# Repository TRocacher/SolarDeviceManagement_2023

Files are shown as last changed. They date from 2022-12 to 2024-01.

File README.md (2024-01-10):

Ce dépôt, en construction, détaille la conception d'un système de pilotage de climatiseurs en fonction de l'excédent de puissance photovoltaïque pour une maison.
Le système s'appuie sur de l'existant :
- Climatiseurs (4) de type Mitsubishi 2kW
- un installation photovoltaïque avec un onduleur Fronius 6kVA SnapInverter associé à un smartMeter triphasé en point d'entrée de réseau ENEDIS

Le système va récupérer les informations de puissance produites par le SmartMeter (via l'onduleur et l'API REST Fournie par Fronius - req HTTP -  ) grâce à une 
carte Raspberry pi pour savoir si de la puissance est disponible.
Un réseau de capteurs est fabriqué (Hardware sous KiCad + Logiciel STM32L41 et STM32F103). Les capteurs communiquent en FSK 433MHz. Ces capteurs sont en fait
des Composants qui jouent le rôle de télécommande Infra Rouge afin de pouvoir commander chaque climatiseur et qui mesurent la température ambiante. Les codes IR
ont été obtenus en sniffant le signal transmis par les télécommandes d'origine.
Une passerelle est également construite, permettant d'échanger avec  les composants distants. Cette passerelle communique en UART avec la Raspberry pi. Cette dernière
hébergera un programme en Python avec une IHM sur écran tactile.
L'ensemble du projet est en cours de conception et réalisation, documenté en SysML pour avoir une vue d'ensemble (Caméo Modeler Magic Draw)
Mots clés : Logiciel embarqué C, Conception électronique, Routage KiCad, SysmL, Réseau de capteur, domotique,  ...

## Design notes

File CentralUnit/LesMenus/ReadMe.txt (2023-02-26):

NB : faire un commit avec nouvelle branche Menu
Réfléchir à la stratégie git

!! modifier la partie Com avec la nouvelle hiérarchie de driver 

/Menu_Src :
Les fonctions sont indépendantes du uC

/Menu_KEIL_103 :
Contient le projet KEIL
	/Src_103 :
	Contient les drivers 103 (Timer qui ne sert pas pour l'instant et UART.c

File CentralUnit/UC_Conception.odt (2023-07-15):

Unité centrale

Conception

# Les menus d'écran

Une LED bicolore indique la disponibilité de la puissance / suggestion charge VE

Mode

Heure

P_Grid

P_Inverter

Temp_Salon, Cons_Salon

Temp_SManger, Cons_SManger

Temp_Entrée, Cons_Entrée

Temp_Couloir, Cons_Couloir

Heure Debut jour/Nuit Salon

Heure Debut jour/Nuit SaManger

Heure Debut jour/Nuit Entree

Heure Debut jour/Nuit Couloir

Loading please wait...

Run

Menu Principal

> Run

> Configuration mode

> VE en charge

> Paramètres

> Diagnostic

En vert, typedef clim

Infos disponibles...

> Mode

> Heure :

> P Enedis W

> P Onduleur W

> Salon °C

> demandé °C

> S à manger °C

> demandé °C

> Entrée °C

> demandé °C

> Couloir °C

> demandé °C

> Salon...

> S à manger …

> Entrée …

> Couloir...

> Heure Début Jour

> Heure Début Nuit

Après 10sec d'inaction

Sous Menu !

## Configuration Mode

- Off : les Remote Devices n'activent plus les climatisations. Il ne font que donner la température
- Mode Vacances: Chaque climatisation possède une consigne de température pour le jour et pour la nuit avec une plage horaire réglable.
- Absence journée: Les consignes en journée, entre 8h et 16h00 sont diminuées de 2°.
- Présence Matinée : Les consignes en journée, entre 12h et 16h00 sont diminuées de 2°.
- Présence Après-midi : Les consignes en journée, entre 8h et 11h00 sont diminuées de 2°
- Mode Forcé : la température est demandée pour toutes les climatisations.
- Mode Voyage : La plage de vacances est spécifiée, les températures sont fixées à 15°C la nuit, 16°C le jour. 2 jours avant la fin des vacances, un mode excédent photovoltaique est programmé pour réchauffer la maison si soleil. 1 journée avant reprise en mode Présence journée
- Mode hebdomadaire : semaine de travail à configurer

NB : la configuration en mode rose rebascule automatiquement en mode hebdomadaire le matin suivant.

NB : pour chacun des 4 modes d'utilisation normale, on précise quelle clim sont utilisées (par défaut toutes). On peut vouloir en enlever selon cheminée ou pellet. On peut aussi privilégier la charge VE : l'excédent PV n'est alors jamais demandé.

Mode

Choisir un mode :

> Off

> Mode Vacances

> Absence Journée

> Présence Matinee

> Présence Après-midi

> Mode Forcé

> Mode Hebdomadaire

> Mode Voyage

Config Mode

Run

## VE en charge

VE en charge

VE en Charge...

> Non

## Paramètres

Typedef Clim

ID

TempJ

TempN

ConsTempJ

ConsTempN

HeureDebJour

HeureDebNuit

DeltaSecRmDvsUC

### Clim

Choisir Clim :

> Clim Salon

> Clim S à manger

> Clim Entrée

> Clim Couloir

paramètres

Paramètres :

> Clim

> Excedent PV

> Vacances

> Appairage

> ResetGénéral

Clim

Clim Salon

Cons Temp J

Saisir Temp :

> ...

Choisir Param :

> Cons Temp J

> Cons Temp N

> Deb Jour

> Deb Nuit

### Excédent PV

Char PrioClim[4]

// contient les ID par ordre de prio

Ordre Prio

Excédent PV

> Ordre Priorité

> Delta °C

Choisir ordre priorité

> SaM/Salon/Ent/Couloir

> Ent/Salon/SaM/Couloir

> Ent/SaM/Salon/Couloir

Excedent PV

DeltaTemp

Temp excédent PV

> Excédent °C :

l'utilisateur choisit le nombre de degrés au dessus de la consigne qu'il s'est donné.= : 1°C, 2°C, 3°C avec un maximum absolu de 22°C. Il spécifie aussi l'odre de priorité des climatisations.

## Diagnostic

## Préparation codage

MNode_Principal_Run -> (Passif)

MNode_Principal_Conf -> (Passif)

MNode_Principal_VE -> (Passif)

MNode_Principal_Param -> (Passif)

MNode_Principal_Diag -> (Passif)

====== Mode Run en entier ============

MNode_Run_Mode (Affichage)

MNode_Run_Heure (Affichage)

MNode_Run_PGrid (Affichage)

MNode_Run_PInv (Affichage)

MNode_Run_InfoClim -> (Passif)

MNode_Run_HeureDebJ (Affichage)

MNode_Run_HeureDebN (Affichage)

MNode_InfoClim_ConsSaM (Affichage)

MNode_InfoClim_TempSaM (Affichage)

MNode_InfoClim_ConsSalon (Affichage)

MNode_InfoClim_TempSalon (Affichage)

MNode_InfoClim_ConsEntree (Affichage)

MNode_InfoClim_TempEntree (Affichage)

MNode_InfoClim_ConsCouloir (Affichage)

MNode_InfoClim_TempCouloir (Affichage)

====== Mode Config en entier ============

MNode_Conf_ModeOff -> (saisie type OK/Discard)

MNode_Conf_ModeForce -> (saisie type OK/Discard)

MNode_Conf_ModeVac -> (saisie type OK/Discard)

MNode_Conf_ModeVoyage -> (saisie type OK/Discard)

MNode_Conf_ModeHebdo -> (saisie type OK/Discard)

MNode_Conf_ModeAbsJour -> (saisie type OK/Discard)

MNode_Conf_ModePresAM -> (saisie type OK/Discard)

MNode_Conf_ModePresPM -> (saisie type OK/Discard)

====== Mode VE en entier ============

MNode_VE-> VE en charge Oui/non (saisie type yn)

====== Mode Param en entier ============

MNode_Param_Clim -> (Passif)

MNode_Param_ExcPV -> (Passif)

MNode_Param_Vac -> (Passif)

MNode_Param_Appairage -> (Passif)

MNode_Param_GenReset -> (Passif)

MNode_Clim_SaM -> (Passif)

MNode_Clim_Salon -> (Passif)

MNode_Clim_Entree -> (Passif)

MNode_Clim_Couloir -> (Passif)

MNode_ConsTempJ -> (Passif)

MNode_Clim_Salon -> (Passif)

# Architecture logicielle

COM_UART

COM_IHM

UART

IHM

Tx,Rx

SPI/I2C

IT ext

ComUART_Status Struct

ComIHM_Status Struct

PrintUART( )

PrintIHM( )

Menu

SystManag

T_SysManag

Menu_Status Struct

SysManag_Status Struct

T_MenuManag

MyAnalog

T_Meas

ControlLoop

Te

I/U meas

I/U meas

Hardware system

GPIO, PWM, DAC...

Ui

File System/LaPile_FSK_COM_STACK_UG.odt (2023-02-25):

User Guide

FSK_COM_STACK

# Architecture de la pile de communication

Sur le schéma ci-dessous, les données applications sont détaillées. Cela peut prêter à confusion. Si l'on s'en tient à l'aspect couche MAC, l'encapsulation « générique » est le suivant :

Phy Frame (ce qui remonte de l'USART et qui arrive en couche PhyUART) : |#####|Len|Data|CheckSum|

MACFrame (ce qui parvient à la couche MAC) : |Data| = |Org@|Dest@|Len'|Data'|

AppliFrame (ce qui remonte à l'application) |Data'|, Len' et Org@ (Dest@ est obligatoirement My)

Dans l'implémentation, la couche MAC est finalement agglomérée à la couche PhyUART sous le nom de MACPhyUART.c/.h

UART (Phy 2)

MAC (My@)

Application

FSK (Phy 1)

- request

- AsyMssg

- data

- Ack

- request

- AsyMssg

- data

- Ack

- request

- AsyMssg

- data

- Ack

PhyUART

- request

- AsyMssg

- data

- Ack

ExchCtrle Frame

|Dest@|ID|Type_LenData|Data|Trial|

MAC Frame

|My@|Dest@|ID|Type_LenData|Data|Trial|

MAC Frame

|Org@|Dest@|ID|Type_LenData|Data|Trial|

ExchCtrle Frame

|Org@|ID|Type_LenData|Data|Trial|

Phy Frame

|#####|Len|Org@|Dest@|ID|Type_LenData|Data|Trial|CheckSum|

UART_FSK_103

- request

- AsyMssg

- data

- Ack

Phy Frame

|#####|Len|Org@|Dest@|ID|Type_LenData|Data|Trial|CheckSum|

# Couches physique

## Vue d'ensemble

La couche physique regroupe :

- FSK (Phy 1) , le module FSK RT606 = matériel hertzien
- UART (Phy 2), l'UART du µC = matériel
- UART_FSK_103 , module driver UART hardware dépendant = logiciel bas niveau
- Phy_UART, module de plus haut niveau de la couche physique = logiciel

RT606

Module FSK

UART

Tx

Rx

/CD

handler

IT ext

IT

RE = 1

Ou 0

IT

Byte received

UART_FSK_103

Tx_Cmde

Rx_Cmde

433MHz

#define

UART_FSK

UseCarrierDetect

CD_GPIO

CD_Pin

Rx_Cmde_GPIO

Rx_Cmde_Pin

Tx_Cmde_GPIO

Tx_Cmde_Pin

Ifdef

UseCarrierDetect

UART_Callback

UART_Receiv

UART_HeaderDetected

PhyUART

PhyUART_FSM

(synchrone)

Timer

(1ms / 100µs)

IT (1ms / 100µs)

systick

( 100µs)

Systickhandler

( Cpt_100us++)

MyTimer

Cpt_100us

(gestion des timeout)

FSKprint

SetReceive

SetTransm

#define

UART_Prio_CD

UART_Prio

PhyUART_FSM_Prio

TIM_PhyUART_FSM

PhyUART_BdRate

StringLenMax

StringLenMin

FSM States

Init

WaitForHeader

ReadingFrame

CheckSum

UpdateMssgForMAC

Framing

SendMssg

Etats du module PhyUART

Ready

Listening

ReceivingMssg

SendingMssg

STM32F103

Config & IO Fcts

MAC layer

Config & IO Fcts

Config & IO Fcts

## Description des fonctions

### UART_FSK_103.c/.h

Le module dépend du hardware.

Deux interruptions sont utilisées :

- réception octet,
- détection de porteuse (optionnelle). Si le UseCarrierDetect est défini, l'UART est bloqué en réception en absence de porteuse. Cela permet d'éviter d'avoir des interruptions UART qui arrivent constamment en présence de bruit.

Les broches :

CD, RxCmde et Tx Cmde sont définies dans le .h.

Tx et Rx sont définies automatiquement, et configurées dans le .c en fonction de l'USART choisie (USART1 , 2 ou 3).

Les fonctions de configurations

Les fonctions IO

### PhyUART.c/.h

La FSM associée est synchrone. Elle est basée sur timer dont la périodicité des interruptions peut prendre deux valeurs, selon le mode dans lequel se trouve la FSM (cf ci-dessous) :

Dans l'état WaitForHeader (majorité du temps), l'échantillonnage de la FSM est de 1ms tant que le Header n'est pas détecté. Dès que celui-ci est détecté (dans le callback UART), le timing descend à 100µs ainsi que pour tous les autres états. Le retour à l'état WaitForHeader se fait toujours après avoir modifié le timing à 1ms.

Les #define

#define StringLenMax 30

#define StringLenMin 7

Ce sont les longueurs qui définissent la chaîne de réception et la celle d'émission.

Les fonctions

## Le flux de données

PhyUART

Etats du module PhyUART

Ready

Listening

ReceivingMssg

SendingMssg

Config & IO Fcts

MAC layer

Erreurs du module PhyUART

NoError

CheckSumError,

LenError,

TimeOutError

OverRunError

char StrReceived[StringLenMax]

InComingMssg[StringLenMax]

CheckSum OK

UART

char StrToSend[StringLenMax]

UART

# La couche MAC

## Vue d'ensemble

Elle est greffée au module PhyUART, le module est renommé : MACPhyUART.

La machine à état est très légèrement modifiée (partie UpdateMssgForMAC), voir ci-dessous.

## Les fonctions de la couche MAC

NB : Si l'utilisateur décide d'exploiter la couche MAC, il utilisera uniquement, exclusivement les fonctions démarrant par MAC. C'est la raison d'être du #define de démarrage de la FSM. Il s'agit effectivement de la même fonction qu'on soit en MAC ou en Phy.

NB : la taille maximale des datas fournies par la couche MAC et livrées à la couche MAC ont une taille maximale qui dérive de la taille maximale fixée au niveau du message UART (plus basse couche physique). Cette taille est définie par StringLenMax dans le .h, initialisée par défaut à 30.

Dans ces conditions, le maximum des datas MAC est de 26.

## Les flux de donnée

Exchange layer

MACPhyUART

Config & IO Fcts

Erreurs du module PhyUART

NoError

CheckSumError,

LenError,

TimeOutError

OverRunError

MACOverRunError

InComingMssg[StringLenMax]

CheckSum OK

UART

char StrToSend[StringLenMax]

UART

char MACStrReceived[StringLenMax]

Match Adress MAC

Etats du module MACPhyUART

Ready

Listening

ReceivingMssg

SendingMssg

char StrReceived[StringLenMax]

## Les erreurs

Niveau Phy

- NoError : tout va bien,
- LenError : Test de Len (premier octet reçu) , la longueur de la chaîne reçue au niveau UART est soit :
  - Trop grande, précisément, supérieure strictement à StringLenMax (define .h),
  - Trop petite, précisément, inférieure strictement à StringLenMin (define .h). En effet, dans notre cas, la chaîne doit contenir au moins Len, @src, @dest,ID, Type_LEN,Trial, CheckSum, soit 7 otctets.

Aucun échantillonnage ne se fait dans IncomingMssg.

- CheckSumError : la détection du header est passée, l'échantillonnage dans IncomingMssg a eu lieu, mais la vérification du checksum a échoué,
- TimeOutError : la trame a commencée à être reconstituée dans IncomingMssg mais elle n'a pas été remplie dans le temps imparti. Le timeout est automatiquement ajusté en fonction du débit de la liaison série. Il est calculer à +10% de la longueur maximale pouvant être reçue.
- OverrunError : cette erreur survient au moment de la mise à jour du flag de réception : si ce dernier était déjà à 1, ce code erreur est activé. Cela signifie que le dernier message Phy n'a pas été lu.

Niveau MAC

- MACOverrunError : cette erreur survient si le message MAC précédent n'a pas été lu.

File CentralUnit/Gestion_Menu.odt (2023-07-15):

Détails de la conception logicielle de l'application

PV

# Overview

SysManag_Status Struct

Menu_Status Struct

T_SysManag

GPIO, PWM, DAC...

ComUART_Status Struct

Tx,Rx

COM_UART

UART

SystManag

ControlLoop

Hardware system

PrintUART( )

Menu_

Manager

ComIHM_Status Struct

Te

I/U meas

SPI/I2C

IT ext

I/U meas

COM_IHM

IHM

MyAnalog

Ui

PrintIHM( )

T_MenuManag

T_Meas

# La gestion des menus

## Expression du besoin

Contraintes

- Les voies UART et IHM sont complètement équivalentes, les menus identiques, l'interaction identique,
- Pour l'IHM, les entrées possibles sont uniquement les caractères : , seules touches disponibles.
- Pour l'UART on définit deux zones du clavier qui au final vont correspondre au commandes type flèches, ces touches sont zsqd pour et olkm pour
- les informations données vers le user sont systématiquement au format du LCD, c'est à dire format écran 4x20 caractères. Pour le LCD (IHM) le menu pourra s'étendre au delà des 4 lignes par un scrolling vertical. Pour l'UART c'est exactement la même chose.

## Les possibilités de l'IHM

C'est ici la fonctionnalité la plus simple, on se contente d'afficher la liste des items du même menu. L'utilisateur n'a qu'à se promener dans les menus avec les flèches (IHM ouUART). Une validation de passer au menu correspondant à l'item. La commande permet de revenir au menu père.

Paramètres

Clim

> Excedent PV

Vacances

Affichage passif

Lors d'une navigation haut / bas, la ligne concernée est identifiée par '>'. A l'arrivée dans un item, le logiciel affiche le titre du menu associé à cet item en première ligne. Ensuite, sur les 3 lignes suivantes, le logiciel analyse s'il existe des item “frères” cad des items accessibles verticalement à afficher. Si oui, l'affichage se fait.

Infos disponibles

Mode : Voyage

> Heure : 12h30

Power Enedis : -2kW

Affichage dynamique

Chaque item indique une information mise à jour régulièrement en background. Les flèches permettent de naviguer dans les items. La flèche de validation de sert à rien. La flèche back permet un retour à l'item père.

La valeur numérique à saisir est indiquée en bas (une valeur par défaut est indiquée). Le premier digit est surligné. Les flèches permettent de changer de chiffre. La flèche de validation permet de valider et de revenir au menu père (curseur dernier digit). La flèche back permet un retour au menu père sans modifier la valeur (curseur premier digit). Les flèches incrémentent / décrémentent le digit surligné. Une valeur minimale et une maximale limitent l'étendue de la valeur saisie.

Saisir une température :

Min : 17

Max : 22

Actual : 20

Type Input Number

VE en charge :

Choix :Yes

> Yes

No

Type Input YesNo

Les flèches indiquent la réponse Yes ou No. La flèche de validation permet de valider et de revenir au menu père. La flèche permet un retour au menu père sans modifier le choix. La valeur actuelle est affichée en seconde ligne.

Les flèches permettent de naviguer sur l'item à classer. La flèche

Classement par priorité

Salle à Manger

> Salon

Entrée

Type Input Sort

valide le choix. Dès lors le préfixe disparaît. Les flèches permettent alors de faire glisser l'item vers le haut ou vers le bas. L'item change alors de place avec celui qui occupait cette place. La flèche refait apparaître le préfixe '>' pour faire de même avec un autre item. Lorsque le préfixe est absent, la flèche permet de revenir au menu en annulant toute modification. Réciproquement, après le placement d'un item, la flèche valide la combinaison élaborée et permet de revenir à l'item précédent.

## Architecture logicielle

Node item d'un menu

(Struc Menu_Node)

Menu_Manager

SystemManager

Menu = items d'un même niveau

Liste chaînée

DataFromSyst

Affichage

DataStringIn

Menu_Status

Menu_ItemUpdate( )

- Update node

- Affichage

Réception new cmd

Réception new data

Com_UART et COM_IHM

L'évolution dans les menus, et d'un menu à l'autre se fait en utilisant une liste chaînée de noeuds, que l'on appelle Menu_Node. Un noeud correspond à un item au sein d'un menu (nb, la notion de menu n'existe pas en tant que variable). Tout est item., peu importe le menu auquel il appartient au final.

La fonction Menu_NodeUpdate( ) est la fonction centrale. C'est elle qui fait évoluer les items dans les deux sens (au sein d'un menu, ou vers un menu père ou fils). Elle est déclenchée par interruption, sur réception d'une nouvelle commande ( ) depuis l'UART ou l'IHM, ou bien sur réception d'une nouvelle donnée à afficher (provenance du SystemManager). Lorsque l'évolution est faite, l'affichage est demandé.

Le systemManager met à jour des données pour affichage. Ces données sont accompagnées par une IT ou un flag qui indique une nouvelle donnée. Cette action ne se fera que dans certaines conditions qui dépendront des items en cours (via MenuStatus).

Les données seront utilisées dans des chaînes dynamiques DataStringIn pour un affichage ultérieur.

Vocabulaire :

Title

Systeme éteint

> Démarrer Bat Chg

> Démarrer MPPT

> Paramètres →

> Gestion Buck

> Gestion Boost

Item

Screen

Menu

Un Item est une ligne de menu que l'on peut sélectionner. Un Menu est l'ensemble des items. Un Screen est la partie du menu qui est effectivement affichée.

Title est le titre du menu inscrit en première ligne.

Chaque Item est relié à des « frères », à un « père », à un « fils ». Liés à des flèches , on trouvera plus précisément :

- un NextItem : ,
- un PreviousItem : ,
- un UpItem : ,
- un DownItem : ,

Exemple :

Paramètres

> Tension a

> Courant b

> Puissance

Systeme éteint

> Démarrer Bat Chg

> Démarrer MPPT

> Paramètres →

> Gestion Buck

> Gestion Boost

Dans cet exemple, l'item Paramètre est tel que :

son title est « Système éteint » type string

son PreviousItem (père) est « Paramètre » . En effet, cet item n'a pas de père, c'est lui même,

son UpItem (frère) est « Démarrer MPPT »,

son DownItem (frère) est « Gestion Buck »,

son NextItem (fils) est « tension a », (et non pas Paramètres)

## Le type structuré Menu_Node

Ce type va nous permettre « d'instancier » les maillons d'une liste chaînée à deux dimensions (verticale et horizontale). Chaque maillon est associé à un item unique (pas un menu) qui doit donc comporter 4 pointeurs vers les maillons connexes ( ). Donc un item un maillon (node).

Le maillon doit donc comporter :

- les 4 champs de navigation dont nous venons de parler,
- les informations nécessaires à l'affichage du screen (quel qu'il soit),
- les informations nécessaires à l'exécution particulière liée à un item.

### les informations nécessaires à l'affichage

Pour mieux comprendre, prenons l'exemple d'un menu générique à 4 lignes :

Titre

> Item a

> Item b

> Item c

> Item d

> Item e

Affichage à

l'entrée sur

Item a :

Titre

> Item a

> Item b

> Item c

> Item d

> Item e

Titre

> Item b

> Item c

> Item d

> Item e

Titre

> Item c

> Item d

> Item e

Titre

> Item c

> Item d

> Item e

Titre

> Item c

> Item d

> Item e

Facile car l'item actif est au milieu et les frères sont au-dessus, au dessous

Sur le scrolling, on voit bien qu'il faudra savoir si l'item est en première ligne, en dernière ou entre les deux. Par ailleurs, il faut prévoir aussi le titre.

Parmi les informations d'affichage, le maillon doit donc contenir :

- le titre du menu
- la position dans le menu {First, Middle, Last}
- le texte à afficher correspondant à l'item (un pointeur sur une chaîne de caractères).

### les informations nécessaires à l'exécution particulière liée à un item

→ Lors de l'affichage, il se peut que la chaîne de caractère soit dynamique. Dans ce cas, le pointeur de chaîne pointe une chaîne réservée en mémoire dont la variable à afficher sera mise à jour par un autre processus. Ce sont les menus type information qui sont concernés :

Titre

> 1.3V

> 3A

> 5W

> 10V

> 1A

Titre

> 1.5V

> 3.1A

> 5W

> 10V

> 2A

Titre

> 1.5V

> 3.1A

> 5W

> 10V

> 2A

Titre

> 2V

> 3.5A

> 8W

> 10V

> 2A

New data

New data

User action

New data

  L'arrivée d'une nouvelle donnée par un autre processus doit déclencher l'évolution du menu (qui va « rester sur place ») et qui provoquera une mise à jour de l'affichage.
  L'affichage devra lancer une fonction particulière puisque la chaîne devra être construite. On insère donc un champ type pointeur de fonction :

→ Lors de la saisie de caractères, l'affichage

  Ici aussi, il faudra prévoir une fonction particulière. L'idée sera d'inviter le user à modifier une valeur déjà programmée, dans un intervalle donné.

Ainsi, il faudra un champs supplémentaire de type pointeur de fonction.

- Pointeur de fonction

### Détail du maillon Menu_Node de la liste chaînée

enum {First, Middle, Last};

typedef struct Menu_Node Menu_Node;

struct Menu_Node {

Menu_Node * NextNode;

Menu_Node * PreviousNode;

Menu_Node * UpNode;

Menu_Node * DownNode;

char * Title;

char MenuPosition;

char * ItemToPrint;

void (*NodeExecFct)(void);

Menu_ParamValTypedef * Param;

};

## L'attribut Menu_Status

Cette variable structurée contient l'état du module Menu. Voici les champs constitutifs (*) :

- ActualNode : qui donne le nœud (donc l'item) actif AVANT l'arrivée d'une nouvelle commande. Lors de l'arrivée d'une commande, le nœud change en fonction des pointeurs H (horizontaux) et V (verticaux),
- Cmde : c'est la dernière commande (filtrée) reçue,
- State : (pour item input) état de la machine à états utilisée,
- LinkPreviousNode : (pour item input) permettre de stocker l'item back,
- StringInputValue[8] : (pour item input) une chaîne de caractères dynamique qui évolue au cours de la saisie du user. Elle comprend un point, jusqu'à 6 digits, le caractère null.
- CursorPos : (pour item input) indique le curseur actif pour la modification du digit correspondant.

typedef enum {Menu_Up, Menu_Down, Menu_Left, Menu_Right } Menu_Cmd;

typedef enum {Entry, SetValue, Discard, Confirm} InputNodeSt;

struct {

Menu_Node * ActualNode;

Menu_Cmd Cmde;

InputNodeSt State;

Menu_Node * LinkPreviousNode;

char StringInputValue[8]; // max 6 digit + '.' + Null

int CursorPos; // 0 sur le premier digit , 6 maxi.

} Menu_Status;

## L'évolution des items, l'exécution de la fonction spécifique

La fonction Menu_NodeUpdate( ) qui sera appelée sur une commande, ou bien sur une demande du module de gestion système, lancera automatiquement la fonction qui lui est associée (via le champ pointeur de fonction NodeExecFct du Menu_Node actif) :

Menu_NodeUpdate( ) :

ou scrutatif sur ComUART / ComIHM

Mémorisation Menu_Status.Cmde

(filtrage touche saisie)

Mise à jour Menu_Status.ActualNode

Exécution NodeExecFct ( )

Le pointeur de fonction NodeExecFct ( ), propre à chaque MenuNode, peut lancer trois fonctions de traitement différentes selon le type du MenuNode :

“Type” de MenuNode | Fonction associée au pointeur :
Item “passif” | Menu_PassivePrint( )
Item “input” | Menu_InputSateMachine( )
Item “output” | Menu_OutputSateMachine( )

## Fonction Menu_PassivePrint( )

Titre

> Item a

> Item b

> Item c

> Item d

> Item e

Affichage à

l'entrée sur

Item a :

Titre

> Item a

> Item b

> Item c

> Item d

> Item e

Titre

> Item b

> Item c

> Item d

> Item e

Titre

> Item c

> Item d

> Item e

Titre

> Item c

> Item d

> Item e

Titre

> Item c

> Item d

> Item e

Facile car l'item actif est au milieu et les frères sont au-dessus, au dessous

L'algorithme

Line1 = Titre

Si la position dans le menu est First :

Affichage du texte de l'Item actuel (n)

S'il existe un menu en dessous, on l'affiche en ligne 3 l'item (n+1)

S'il existe un menu encore en dessous, on l'affiche en ligne 4 l'item (n+2)

Si la position dans le menu est Middle :

Affichage en ligne 2 Item actuel (n-1)

Affichage en ligne 3 Item actuel (n)

Affichage en ligne 4 Item actuel (n+1)

Si la position dans le menu est Last:

S'il existe un menu encore en dessus,

Affichage en ligne 2 l'item (n-2)

Affichage en ligne 3 l'item (n-1)

Affichage en ligne 4 l'item actuel (n)

Sinon (il n'existe pas d'item n-2)

Affichage en ligne 2 l'item (n-1)

Affichage en ligne 3 l'item actuel (n)

Clr ligne 4

Fin Si

## Fonction Menu_InputStateMachine( )

### Variable supplémentaire

Le user (module supérieur) connaît les divers Menu_Node. (il sont déclarés dans Menu.h et c'est lui qui les a créés dans Menu.c).

Chaque Menu_Node possède un champ spécifique pour les paramètres (input à saisir, plus précisément, valeur à modifier puisqu'une valeur en cours est systématiquement fournie):

Menu_ParamValTypedef * Param;

Pour la grande majorité des Menu_Node, ce champ sera inutile (menu passif). Dans ce cas, on initialisera systématiquement le champs &ParamNull.

Structure param :

typedef struct

{

float Val; la valeur en question

float MinVal;

float MaxVal;

char DigitNb; le nbre de digit qui forme le nombre (point non compris)

char DecimalNb; le nbre de décimales derrière le point

char NewUserInputFlag; indique que Val vient d'être modifiée par le user via le menu saisi correspondant

} Menu_ParamValTypedef;

### Scénario de saisie

exemple avec MenuNodeInput_VoltParam

Menu.c

Menu.h

ModuleSup.c

(SystManag.c)

MenuNodeInput_VoltParam

Menu_IsNewParamValue(Menu_ItemVoltParam)

1 (donc oui, une nvelle valeur présente)

Menu_ClearNewParamFlag()

NewVal

Param

Menu_GetParamValue(Menu_ItemVoltParam)

Valeur récupérée

### Evolution des écrans dans la procédure de saisie

Voici l'enchaînement typique des écrans que devrait voir le user quand il entre dans un tel item :

(exemple : le MenuNode « passif » MenuNodePassive_3_1 permet d'accéder au MenuNode « input » MenuNodeInput_VoltParam)

NB : en bleu, les infos user (soit fixées lors de la définition des MenuNodes, soit données dynamiques).

La figure ci-dessus montre la complexité vis à vis d'une simple navigation dans des menus passifs :

Param setting

>Voltage Level

Menu b

Menu c

Volt Param [V] …:

Min : 12.00

Max: 13.00

Actual : 12.50

<Right> & (curseur!= maxpos)

<Left> & (curseur!= 0)

<Up>

<Down>

Réglage de chaque digit avec les flèches

Discard changes ?

Yes : click Left

No : click Right

Waiting ...

Confirm changes ?

Yes : click Right

No : click Left

Waiting ...

MenuNodePassive_3_1

<Right>

<Left> & (curseur =0)

<Right>

<Left>

<Right> & (curseur =maxpos)

<Left>

Any key

<Up>

| <Down>

<Right> && Valeur KO

Value out of Range

Enter new Value...

<Rightt> && Valeur OK

MenuNodeInput_VoltParam

- le passage d'un MenuNode à un autre ne se fait pas sur la même commande, il faut donc modifier dynamiquement les pointeurs horizontaux et verticaux,
- Au sein de MenuNodeInput_VoltParam, on voit clairement des états différents, il faut donc construire une machine à états.

Trois fonctions d'affichage seront utilisées :

- MenuInput_PrintParam ( ): affiche les 4 lignes dynamique à partir :
  - des champs MinVal et MaxVal de Param (MenuNodeInput en cours),
  - du champ StringInputValue[8] de la variable d'état
- MenuInput_PrintDiscard ( ): screen statique,
- MenuInput_PrintConfirm ( ): screen statique.

### Graphe d'états associé à la fonction Menu_ImputStateMachine ()

= Key just stroken

Menu_Status.ActualNode

=

MenuNodePassive x

MenuNodePassive x

Cmde = <Right>

&& State=Entry

Menu_InputStateMachine()

Entry

Algo : State ← SetValue

Cmde = any

&&

State=SetValue

SetValue

Algo : State ← SetValue / State ← Discad / State ← Confirm

Cmde = any

&&

State = SetValue

Cmde = any

&& State=Confirm

Cmde = any

&&

State = Discard

.Cmde = any

&&

State= SetValue

Cmde =<Left>

&& State=SetValue

.Cmde =any

&& Val KO

&& SetValue

Confirm

Discard

Algo : Forçage ActualMenuNode / State ← SetValue

Algo : Forçage ActualMenuNode / State ← SetValue

.Cmde = <Up> || <Down>

.Cmde = <Up> || <Down>

Menu_Status.Cmde =<Left>

.Cmde =<Right>

&& Val OK

Menu_Status.ActualNode

=

MenuNodePassive x

MenuNodePassive x

NB : les états Discard et Confirm font évoluer un MenuNode sans action sur une touche.

State = Entry, Algo :

Blocage de MenuNodeInput avec linkNode

Affectation de la valeur param : StringInputValue[8] ← Param.Val , via float2Str ()

Affichage : MenuInput_PrintParam ( )

State = SetValue

State = SetValue, Algo

Si Menu_Status.Cmde = <Up> ou <Down> (défilement digit)

digit + ou – %10 sur le CurorPos actuel

MenuInput_PrintParam ( )

Fin Si

Si Menu_Status.Cmde = <Left> ou <Right> (déplacement curseur dans les limites des digits)

CursorPos + ou -

MenuInput_PrintParam ( )

Fin Si

Si Menu_Status.Cmde = <Left> && CursorPos=0 (Demande Discard)

MenuInput_PrintDiscard ( )

State = Discard

Fin Si

Si Menu_Status.Cmde = <Right> && CursorPos=PosMax (Demande Confirm)

MenuInput_PrintConfirm ( )

State = Confirm

Fin Si

State = Confirm, Algo :

State = Discard, Algo :

Si Menu_Status.Cmde = <Left>

libérer l'item input actuel (comme il était)

Remettre State Entry

ActualNode=père

Menu_PassivePrint ( )

Sinon si Menu_Status.Cmde = <Right>

MenuInput_PrintParam ( )

State = SetValue

FinSi

Si Menu_Status.Cmde = <Right>

StringInputValue[8] → valeur float

Si Valeur dans l'intervalle

StringInputValue[8] → Param.Val

libérer l'item input actuel (comme il était)

Remettre State Entry

ActualNode=père

Menu_PassivePrint ( )

Sinon

MenuInput_PrintRetry ( )

State = Retry

Fin Si

Sinon, si Menu_Status.Cmde = <Left>

MenuInput_PrintParam ( )

State = SetValue

Fin Si

State = Retry, Algo :

Curseur Pos = 0

State = SetValue

Affichage : MenuInput_PrintParam ( )

# Comment utiliser le module Menu ?

## Rappels

Le module est fait pour être utilisé dans n'importe quel projet avec 3 fonctionnalités principales :

- création d'autant d'tem que l'on veut pour ses menus,
- gestion des menus passifs (navigation dans les menus),
- menu pouvant permettre la saisie d'une donnée décimale, digit par digit,
- menu avec items dynamiques pouvant afficher des données à la volée.

Les entrées sont limitées à : , les sorties sont sur 4 lignes / 20 caractères. Les menus sont en fait gérés par une liste chaînée d'items. Autrement dit, il y a autant d'éléments dans la chaîne (Menu_Node), que d'item dans l'ensemble des menus.

## Etapes de programmation

### Procédure systématique :

- Le user construit son organisation de menu, et donc, définit tous les items des divers menus. A chaque item, il crée un Menu_Node :
  - déclaration dans le .h : dans le .h des variables Menu_Nodes pour que le module supérieur puisse agir dessus :
    - pour savoir où en est le menu pour interagir avec le système,
    - pour passer des paramètres à modifier lors de menu type saisi (le paramètre fait partie des champs d'un Menu_Node.
      Exemple (définition à faire en tête de la zone : USER ZONE BEGIN ) :
      extern Menu_Node MenuNodeInput_30;
  - Définitions dans le .c (balise User Zone au début du fichier) des diverses variables Menu_Node,
      NB : Bien que non obligatoire, il convient de convenir d'une notation pour ces variables :
    - Item type « passif » : MenuNodePassive_...
    - Item type « saisie » : MenuNodeInput_...
    - Item type « affichage valeurs » : MenuNodeOutput_...
      Exemple :
      Menu_Node MenuNodeInput_30;
  - remplissage dans le .c des champs de la structure de chaque Menu_Node définis de manière à réaliser l'architecture de menu dans sa globalité,
      Exemple :
      MenuNodeInput_30.UpNode=&MenuNodeInput_30;

MenuNodeInput_30.NextNode=&MenuNodeInput_30;

MenuNodeInput_30.DownNode=&MenuNodeInput_30;

MenuNodeInput_30.PreviousNode=&MenuNodePassive_3_5;

MenuNodeInput_30.MenuPosition=Last;

MenuNodeInput_30.Title="Volt Param 30... ";

MenuNodeInput_30.ItemToPrint =" Actual : ";

MenuNodeInput_30.NodeExecFct=Menu_InputStateMachine;

MenuNodeInput_30.Param=&Param_21;

### Procédure liée au menu type saisie :

Un paramètre est une valeur au départ fournie par le user, accompagnée d'un min et d'un max :

- de manière statique (comme expliqué §3.2.1) : lors du remplissage des Menu_Node, on indique en dur le paramètre (balise User Zone au début du fichier).
- De manière dynamique par appel à une fonction d'écriture spécifique du paramètre dans les Menu_Node.

L'utilisateur doit définir le mode d'affichage du float, via les champs (verts) :

typedef struct

{

float Val; la valeur en question

float MinVal;

float MaxVal;

char DigitNb; le nbre de digit qui forme le nombre (point non compris)

char DecimalNb; le nbre de décimales derrière le point

char NewUserInputFlag; indique que Val vient d'être modifiée par le user via le menu saisi correspondant

} Menu_ParamValTypedef;

Val, MinVal, MaxVal peuvent être saisie n'importe comment.

Le format d'affichage est défini par :

- DigitNb : de 1 à 6,
- DecimalNb: de 0 à 3
- on doit toujours respecter DecimalNb > DigitNb

NB : Si ces consignes ne sont pas respectées, à l'exécution, dès qu'une conversion float / string ou l'inverse est demandée, un message d'erreur indique un plantage à cause de cela, avec un while(1) à la clé....

→ à la charge de l'utilisateur de faire attention

A titre d'information voici les formats possibles :

formats | 1 | 2 | 3 | 4 | 5 | 6
0 | x. | xx. | xxx. | xxxx. | xxxxx. | xxxxxx.
1 | | x.x | xx.x | xxx.x | xxxx.x | xxxxx.x
2 | | | x.xx | xx.xx | xxx.xx | xxxx.xx
3 | | | | x.xxx | xx.xxx | xxx.xxx

      Exemple (définition à faire en tête de la zone : USER ZONE BEGIN )
      Menu_ParamValTypedef Param_30;
      Exemple (définition à faire en tête de la zone : USER ZONE BEGIN )
      Param_30.Val=150;

Param_30.MinVal=-100;

Param_30.MaxVal=500;

Param_30.NewUserInputFlag=0;

Param_30.DigitNb=3;

Param_30.DecimalNb=0;

Test exhaustif des formats

18 menus à faire...

MenuNodeInput_10 (1,0 à 3,0)

MenuNodeInput_20, MenuNodeInput_21, (-10,0 à 99,0)

MenuNodeInput_30, MenuNodeInput_31,MenuNodeInput_32 (-5,0 à 300,0)

MenuNodeInput_40, MenuNodeInput_41,MenuNodeInput_42, MenuNodeInput_43 (-1000,0 à 3000,0)

MenuNodeInput_50, MenuNodeInput_51,MenuNodeInput_52, MenuNodeInput_53 (-100,0 à 30000,0)

MenuNodeInput_60, MenuNodeInput_61,MenuNodeInput_62, MenuNodeInput_63 (-52,0 à 45,0)

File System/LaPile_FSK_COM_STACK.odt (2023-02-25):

Conception d'un protocole et implémentation

FSK_COM_STACK

NB : SEULES les couches MAC et PhyUART ont été réalisées, la couche la plus haute, « ExchangeCtrl » est finalement trop complexe pour pas grand chose de plus.

Voir la version _UG (User Guide) pour ce qui est réellement réalisé et validé.

# Présentation

On souhaite construire une "pile" de communication had-hoc pour faire communiquer des dispositifs en HF, en mode mult-maître. Ci-dessous un diagramme de séquence qui montre le service à rendre :

Part A

Part B

Échange synchrone

Message asynchrone

requête

data

mssg Asy

Niveau applicatif

Du point de vue système (SysML), un échange synchrone démarre par l'émetteur avec un flèche pleine. C'est une requête. Part A attend une réponse (flèche en pointillée) de Part B.

Un message asynchrone, est un message qui n'attend pas de retour.

Accès au médium :

Le système est par défaut en écoute. Un message est émis dès lors que le système n'est pas en train de recevoir un trame.

Si lors d'une émission, un device est en train d'émettre une trame (multi maître), cette dernière sera irrémédiablement perdue. Il n'y a pas moyen de détecter si une collision a eu lieu. Un CSMA/CD est donc impossible. Il faut tenter d'éviter au maximum une collision CSMA/CA. Bien entendu on ne va pas faire un WIFI mais cette idée étant présente à l'esprit, la pile que l'on va concevoir doit mettre l'accent sur la fiabilité du système, qui par nature, ne l'est pas du tout !

La pile de communication envisagée doit permettre :

- la réalisation de ces deux types d'échange (synchrone, asynchrone),
- un comportement logiciel non bloquant vis à vis de l'application : l'application ne doit pas attendre les données après une requête (ou plutôt, l'attente doit pouvoir se faire en non bloquant). Cette gestion est justement confiée à la pile de communication,
- une robustesse pour garantir au maximum la transmission des messages en utilisant :
  - un préambule (bits) propre au réseau crée afin de filtrer les devices appartenant au réseau de tout autre communication 433MHz (télécommandes quelconques, domotique...),
  - un accusé de réception systématique à tout message envoyé (les données pour une requête, ou un acquittement simple pour un message asynchrone),
  - une répétition de l'envoi des messages si un délai est dépassé (Time Out)

# Architecture de la pile de communication

Exemple : L'application initie un échange caractérisé par son ID

UART (Phy 2)

MAC (My@)

ExchangeCtrle

Application

Exchange : ID n°

- requests

- data

- AsyMssg

FSK (Phy 1)

- request

- AsyMssg

- data

- Ack

- request

- AsyMssg

- data

- Ack

- request

- AsyMssg

- data

- Ack

Phy_UART

- request

- AsyMssg

- data

- Ack

ExchCtrle Frame

|Dest@|ID|Type_LenData|Data|Trial|

MAC Frame

|My@|Dest@|ID|Type_LenData|Data|Trial|

MAC Frame

|Org@|Dest@|ID|Type_LenData|Data|Trial|

ExchCtrle Frame

|Org@|ID|Type_LenData|Data|Trial|

Phy Frame

|#####|Len|Org@|Dest@|ID|Type_LenData|Data|Trial|CheckSum|

Phy Frame

|#####|Len|Org@|Dest@|ID|Type_LenData|Data|Trial|CheckSum|

Notons que les échanges au niveau de la couche "ExchangeControl" se font nécessairement en mode synchrone dans le sens où, même un message asynchrone sera acquitté par le receveur pour renforcer la qualité de la liaison.

## Les trames du protocole

Le protocole est fait pour gérer jusqu'à 256 entités qui échangent en FSK. Les adresses s'étendent donc de 0 à 0xFE, avec OxFF réservée pour le broadcast. Org@ et Dest@ caractérisent, pour une transmission donnée, l'entité à l'origine du message et celle qui en est destinataire.

### Trame ExchangeLayer Frame

La trame se situe entre la couche ExchangeLayer et la couche MAC.

Constitution :

|Dest@| ID|Type_LenData|Data|Trial| ou |Org@|ID|Type_LenData|Data|Trial|

champ Dest/Org@ (8bits): Selon le sens, c'est l'adresse à qui est destiné le message, ou l'adresse source du message,

ID| (8bits) : C'est le numéro de l'échange en cours. Il permet d'identifier une réponse à une requête ou un acquittement à un message asynchrone. Il caractérise de manière univoque un échange.

Type_LenData : Les 6 bits de poids faibles représentent la longueur de données, c'est à dire le nombre de caractères qui constituent la donnée (63 maximum). Les deux bits de poids fort indiquent le type de trame :

- 00 = Req (Requête),
- 01 = Data,
- 10 = AsyMssg (Message asynchrone),
- 11 = Ack

Data : les données proprement dites, succession de caractères 8 bits qui ont un sens ordonnée pour l'application en amont. A ce niveau, c'est un simple bloc de données 8 bits, dont le nombre est indiqué dans le champ précédent.

Trial(8bits) : Nombre d'essais concernant l'échange en cours (depuis la première émission de la requête ou la première émission du message asynchrone). 1 à 254 essais possibles.

NB : la valeur 0xFF (-1) est particulière. Lors d'une réception de Data ou Ack (suite à une requête ou message asychrone), cette valeur indique que le message est bien arrivé au destinataire, mais pas jusqu'à l'application destinataire. Le message s'est donc arrêté à la couche Exchange du destinataire. Ce retour se fait si l'application n'a pas répondu au bout d'un certain temps.

### Trame MAC Frame

La trame se situe entre la couche MAC et la couche Phy_UART

Constitution :

En descendant, transmission :

|My@|Dest@|ID|Type_LenData|Data|Trial|

En remontant, réception :

|Org@|Dest@|ID|Type_LenData|Data|Trial|

Pour chacun des deux types de trame :

- dans le sens d'une transmission, la couche MAC aura encapsulé la trame précédente pour y ajouter en tête l'adresse origine du message, à savoir My@ (traduire mon adresse, celle de l'entité en question, connue par la couche MAC),
- dans le sens d'une réception, la couche UART présentant l'adresse de destination, Dest@, la couche MAC compare celle-ci avec My@. Si la comparaison est bonne, le message est transmis vers la couche supérieure à la couche MAC, à savoir la couche ExchangeControl (le message est alors décapsulé, on enlève Dest@ qui ne sert plus). Dans le cas contraire, le message est écarté.

### Trame Phy Frame

La trame se situe entre la couche Phy_UART et l'UART

Constitution :

En descendant, transmission :

|#####|Len||My@|Dest@|ID|Type_LenData|Data|Trial|CheckSum|

En remontant, réception :

|#####|Len |Dest@|Org@|ID|Type_LenData|Data|Trial|CheckSum|

La couche Driver UART va encapsuler (décapsuler) la trame issu de (allant vers) la couche MAC. Pour l'encapsulation on ajoute les champs :

préambule ##### (5 octets, 40 bits) : ils sont nécessaires pour filtrer les autres transmission à 433MHz.

Len (1octet) : c'est la longueur totale de la trame, hors préembule #####. Il inclut le checksum.

Checksum (1 octet) : somme de l'ensemble (hors checksum) modulo 256.

### Interaction au niveau de la couche ExchangeControl :

Part A

Part B

Échange synchrone

mssg Asy ( m)

Niveau ExchangeCtrl

Requête ( n)

Data (ou Trial = -1)

Data (ou Trial = -1)

A ce niveau, requête ou message asynchrone sont en fait synchrones et seront relancés n fois si nécessaire pour assurer la bonne remise du message.

# Mécanisme logiciel de la pile de communication

La pile utilisera le systick timer pour gérer tout ce qui est de l'ordre du timeout. Egalement, les trois couches logicielle (UART Driver, MAC, ExchangeLayer ) seront gérées par une machine à état.

## La gestion des timeout

Le systick sera cadencé à 100µs. Deux fonctions seront utilisées :

- SystickStart() : initialise un compteur et lance le systick
- SystickGet() : renvoie la valeur du compteur 100us.

Chaque brique logicielle xxx qui aura besoin d'un Timeout devra :

- utiliser une fonction nommée xxx_TimeOut_Start(TimeOut_ms) : mémorise quelque part la valeur courante du systick à laquelle on ajoute 10 * TimeOut_ms (pour passer en multiple de 100µs),
- utiliser une fonction nommée xxx_GetTimeOut_Status() : compare la valeur courante du Systick avec la valeur mémorisée. Donne 0 ou 1 selon que le temps est échu ou pas.

Attention, la comparaison devra se faire en signé pour gérer correctement le débordement.

Exemple (systick 24bits) : valeur maximale = 0xFFFFFF 1677 secondes (27,78 heures).

Supposons que la mémorisation soit 0xFFFFFF (-1 en extension 32 bits). Supposons que le Timeout voulu soit de 2ms, la valeur attendue est donc 0xFFFFFFFF + 10*2 = -1+20=19.

La comparaison se passera bien.

En résumé :

Initialisation générale : SystickStart()

Exemple , la brique xxx veut lancer un TimeOut à 3ms :

xxx_TimeOut_Start(1) ( fonction qui appellera SystickGet() puis ajoutera 3*10, le tout mémorisé)

De manière récurrente dans la brique xxx, on lancera xxx_GetTimeOut_Status() pour savoir si le temps est échu ou pas.

## Machine à état fini (FSM)

Pour une brique logicielle xxx, on utilisera les fonctions :

- xxx_FSM_Reset() : met la machine à état dans son état initial (Init) qui ne fait strictement rien,
- xxx_FSM_Start() : sort de l'état initial (transition Start active), active le graphe d'état. La machine à état est fonctionnelle,
- xxx_FSM_Progress() : Fait progresser d'un état la machine à état. Doit être appelée régulièrement sous IT. Ne dure pas. Très courte. Met à jour les sorties en fin d'exécution en fonction de l'état (modèle machine de Moore)

Pour pouvoir fonctionner, la brique logicielle doit posséder une variable état de type énumérée qui représentera l'état en cours. Egalement, elle utilisera une structure pour les transitions dont la nature sera propre à chaque machine à état.

- xxx_FSM_CurrentState : char
- xxx_FSM_Trans :Structure

## Exécution de la pile

Le fonctionnement de chaque couche doit se faire de manière parallèle (ou presque...). Pour cela, il sera nécessaire de :

- utiliser le systick pour gérer le timeout de chaque couche,
- utiliser un autre timer pour gérer TOUTES les machines à état sous forme interruptive. La routine d'interruption FSM doit lancer en suivant toutes les progressions des FSM,
- L'interruption FSM est logée dans la couche la plus haute de la pile, donc dans ExchangeCtrl.
- La FSM au niveau UART_PHY est la plus critique (il ne faut pas louper un caractère). Voir partie 6.6 pour fixer le timing. Il est fort probable qu'il faille un timer spécifique en IT pour cette FSM de manière à pouvoir interrompre une autre, de couche supérieure moins critique.

Cette routine d'interruption est essentielle. Le nombre de FSM à gérer est variable. On utilise deux variables pour connaître puis gérer les échanges :

- Exchange ExchTab[10]. Ce tableau contient 10 échanges contenant chacun tout ce qui est nécessaire à l'exécution (voir plus loin la structure Exchange). La structure Exchange contient la FSM propre à l'échange, repéré par son index i (0 à 9). Si son status est Free, alors il est libre pour un nouvel échange. ainsi, l'interruption lancera toutes les FSM des échanges dont le champs Statut sera différent de Free.
- ExchangeLayer Status : Voir autre doc, chapitre 1.3

Interruption FSM :

Pour Index de 0 à 9

Free

Free

_

Free

_

_

Free

0

1

…

9

Index i

EchTab

Status

FSM

Si ExchTab[Index] != free

xx_FSM_Progress(Index)

Fin si

Fin Pour

## Architecture logicielle

La pile de communication que nous développons pour l'application domotique doit avoir un nom :

FSK_Com_Stack.

L'architecture logicielle sera la suivante

ExchangeCtrl

MAC

Phy_UART

# La couche ExchangeControl

Si on veut généraliser un peu, il faudrait que la couche ExchangeControl puisse gérer plusieurs communications à la fois. Cela implique de mémoriser tout le contexte lié à un échange.

Ce contexte doit réunir l'état de l'échange, ses caractéristiques (message de départ, message de retour), mais également tout ce qui concerne le graphe d'état associé. A un instant donné, on peut avoir plusieurs FSM qui tournent en même temps.

On appellera Exchange (ou échange), un contexte qui réunit tout ce qui concerne :

- une requête, message asynchrone, une donnée ou un simple accusé de réception.
- une FSM associée,
- un status

Créer un échange, c'est créer une donnée complexe contenant le contexte de l'échange. Clôturer, détruire un échange c'est libérer la donnée contenant le contexte associé, la remettre à zéro, placer son Satus à Free..

La pile construite contiendra 10 échanges en même temps maximum à chaque instant.

## Définition des types et variables de la couche ExchangeCtrl

Plus précisément, un échange est une donnée complexe, structurée en champs. Pour rappel voici la trame traitée dans la couche ExchangeLayer :

|Dest@|ID|Type_LenData|Data|Trial| ou |Dest@|ID|Type_LenData|Data|Trial|

Le type échange sous forme de ligne :

Status | Org/dest Adr | ID | Type | LenData | Data[30] | Trial | TimeOutDate | FSM_CurrentState | FSM_Trans

Type : Exchange :

- Enum Status
- char OrgAdr
- char DestAdr Les champs bleus permettent la gestion de la FSM associée à l'échange
- char ID
- char Type
- char LenData
- char Data[30] 30 ?
- char Trial
- int TimeOutDate
- char FSM_CurrentState
- FSM_Transition_Struct FSM_Trans

### Gestion des FSM

Il existera 4 FSM distinctes, Request_FSM, AsyMssg_FSM, Data_FSM et Ack_FSM. Selon le type d'échange, l'une des quatre sera lancée.

Chaque échange a son propre état courant. Il possède aussi son ensemble de transition. Les 4 FSM partagent cet ensemble. Il est donc nécessaire de recenser et nommer (enum) TOUTES les transitions. Certaines auront un nom commun comme Start par exemple.

void Exch_FSM_Reset (int Exch_Index)

ExchTab[Exch_Index] .CurrentState=Init

void Exch_FSM_Start(int Exch_Index)

ExchTab[Exch_Index] .FSM_Trans.Start=1

void Exch_FSM_Progress (int Exch_Index)

Connaissant Exch_Index, on extrait Type

Swich type:

Case type == Req

Req_FSM_Progress(int Exch_Index)

Case type == AsyMssg

AsyMssg_FSM_Progress(int Exch_Index)

Case type == Data

Data_FSM_Progress(int Exch_Index)

Others (Ack )

Ack_FSM_Progress(int Exch_Index)

Fin switch

## L'échange de type requête : émissaire de la requête

### Les étapes de l'échange ...

Device A

Device B

Appli

ExchangeCtrl

Appli

ExchangeCtrl

2- Create Exch n°x

4- Create Exch n°y

3- Req (ID=x)

5- Req

1- Req (ID=x)

6- Data

7- Kill Exch n°y

8- Data (ID=x)

9- Data

10- Kill Exch n°x

3’- retry n

Req

Data

Fig x : échange typique d'une requête : focus sur l'initiateur de la requête, émission

### Côté A : les étapes 1-3 , 6-8

1. L'application envoie une requête à la couche ExchangeLayer en précisant l'ID de la requête (de manière univoque).
2. La couche d'échange cherche une entrée libre dans la table.
  - Si c'est OK, l'échange est crée, le message encapsulé
  - Sinon message d'erreur vers l'application
3. La trame est passé à MAC avec gestion des essais (par exemple jusqu'à 5). Si erreur l'application est informée
8. La MAC a passé la data à la sous-couche MAC2ExchSubLayer (filtrage adresse). Cette sous-couche aura aussi filtré l'ID ainsi que la nature Data de la trame reçue (cf FSM de réception). Le statut de l'échange correspondant est modifié de sorte à ce que l'application puisse savoir que la donnée est arrivée.
9. La donnée est lue par l'application.
10. L'échange est détruit (status passe à Free).

### La State Machine Request FSM

Appli

Exchange Layer

Request_FSM

Status | Org/dest Adr | ID x | Type | LenData | Data[30] | Trial | TimeOutDate | FSM_CurrentState | FSM_Trans -

Les transitions de la FSM sont dans l'échange x. Ces transitions peuvent être modifiées par les états de la FSM mais aussi par l'application (via des fonctions de lecture de données par exemple), par la sous-couche MAC2ExchSubLayer, lors d'une réception depuis la MAC.

L'état actif de la FSM est également l'un des champs de l'échange.

Le status de l'échange est modifié par la FSM, en fonction de l'état actif.

## L'échange de type Message Asynchrone : émissaire du message

### Les étapes de l'échange ...

### Côté A...

Device A

Device B

Appli

ExchangeCtrl

Appli

ExchangeCtrl

2- Create Exch n°x

4- Create Exch n°y

3-Mssg (ID=x)

5- Mssg

1- Mssg (ID=x)

5- Ack

7- Kill Exch n°y

6- Ack(ID=x)

7- Ack

8- Kill Exch n°x

3’- retry n

Message Asyn

Ack

Fig x : échange typique d'un message asynchrone : focus sur l'initiateur du message, émission

1. L'application envoie un message asynchrone à la couche Exchange Layer en précisant l'ID du message (de manière univoque).
2. La couche d'échange cherche une entrée libre dans la table.
3. Si c'est OK, l'échange est crée, le message encapsulé
4. Sinon message d'erreur vers l'application
5. La trame est passé à MAC avec gestion des essais (par exemple jusqu'à 5). Si erreur l'application est informée
6. La MAC a passé un Ack à la sous-couche MAC2ExchSubLayer (filtrage adresse). Cette sous-couche aura aussi filtré l'ID ainsi que la nature Ack de la trame reçue (cf FSM de réception). Le statut de l'échange correspondant est modifié de sorte à ce que l'application puisse savoir que la donnée est arrivée.
7. L'ack est lue par l'application ou pas. Si non lu au bout d'un certain temps on passe à l'étape 8. Cette non lecture est la véritable nature d'un message asynchrone. On laisse à l'application le choix de lire ou pas l'acquittement.
8. L'échange est détruit (status passe à Free).

### La state Machine AsyMssg_FSM

## La réception

Elle se décompose en 2 niveaux comme le montre la figure ci-dessous. Deux sous-couches :

- MAC2ExchSubLayer
- Exch2AppliSubLayer

### Architecture

Exchange Layer

ExchLayerFrame

MAC layer

MAC2ExchSubLayer

Free

Free

_

Free

_

_

Free

0

1

…

9

EchIndex

char ExchTab[10]

Status

FSM

Exch2AppliSubLayer

FSM :

Exch2AppliLayerSubLayer_FSM

FSM Transition

Variables de ExchLayerStatus

Code Erreur

NoError

IDMismatch

ExchTabIsFull

struct ExchLayerStatus

ExchLayerExecution

Interruption FSM :

Mac2ExchRecep_FSM_Prgress()

Pour Index de 0 à 9

Si ExchTab[Index] != free

xx_FSM_Progress(Index)

Fin si

Fin Pour

Appli

Req / AsyMssg

Data / Ack

char NewFrameFromMAC 0/1

char CurrentExchQte 0-9

ELF_Struct TransmExchLayerFrame

|Dest@| ID|Type_LenData|Data|Trial|

ELF_Struct ReceptExchLayerFrame

|Org@| ID|Type_LenData|Data|Trial|

char Error

char FSM_State

char FSM_Transition

char NewFrameToMAC 0/1

FSM List :

FSM_Req

FSM_AsyMssg

FSM_Data

FSM_Ack

FSM Transition

Start

ReqFromMAC

FSM_Trans_CreateExchOK

AsyMssgFromMAC

DataFromMAC

AckFromMAC

ReqAsyMssgFromMAC

DataFromAppli

FSM Status : Free, Ready, IDMismatch, TabFull, WaitOnDataAckRecept, FailToReaceive, DataAckJustReceived, WaitForAppData, WaitForAppAck,

### Réception depuis MAC : Exch2AppliSubLayer_FSM

La réception intervient dans 4 situations :

- A (émissaire d'une requête) attend une trame Data de la part de B,
- A (émissaire d'un message asynchrone) attend une trame Ack de la part de B,
- B destinataire d'une requête, attend une trame de type requête de la part de A,
- B destinataire d'un message asynchrone attend une trame de type message asynchrone de la part de A,

Ainsi, la sous-couche MAC2ExchSubLayer va gérer les messages filtrés de MAC (@ destination = my), et va se charger de créer un échange (deux derniers cas), ou mettre à jour les échanges existants (deux premiers cas).

Principe : Une fois lancée, la FSM attend un nouveau message de la MAC. Celui ci est analysé (voir algorithme associé à l'état ExchchangeCreateUpdate) . Dès lors, un attente est lancée pour laisser à la couche applicative de gérer ce message. Durant ce laps de temps toute nouvelle trame arrivant depuis la MAC n'est pas traitée. Passé ce temps la FSM se remet en attente.

ExchLayerStatus.NewFrameFromMAC=0
Si Type == Data (Update)

Si Echange existe (vérification),

mettre à jour (en particulier les champs Data et FSM_Trans. DataFromMAC=1)

Sinon Status.Erreur = IDMismatch

Si Type == Ack (Update)

Si Echange existe (vérification),

mettre à jour (en particulier les champs Data et FSM_Trans. AckFromMAC=1)

Sinon Status.Erreur = IDMismatch

Si Type == Req (Creation)
Si table not full

mettre à jour (en particulier les champs Data et FSM_Trans. Start=1 et Type = Data)
Sinon Status.Erreur = ExchTabIsFull

Si Type == AsyMssg (Creation)
Si table not full

mettre à jour (en particulier les champs Data et FSM_Trans. Start=1 et Type = Ack)
Sinon Status.Erreur = ExchTabIsFull

Fin si

Les 4 situations de réception sont claires vis à vis de la sous-couche Exch2AppliSubLayer grâce au travail de réception de la sous-couche MAC2Exch2SubLayer : chaque échange est à jour (soit nouvellement créé, soit mis à jour).

Pour les deux premières (cf 1.3.2) les FSM Request_FSM et AsyMssg_FSM sont débloquées et peuvent poursuivre leur route.

Pour les deux autres, l'une ou l'autre des FSM suivantes auront été lancées(via un start dans l'échange). Le choix de la FSM se fera via le type de l'échange :

Si Type = Data (suite à une réception de type Req), ce sera Data_FSM qui sera lancée,

Si Type = Ack (suite à une réception de type AsyMssg), ce sera AsyMssg_FSM qui sera lancée.

## Les échanges de type Data et Ack

### Les étapes de l'échange …

Il s'agit ici de se situer au niveau du device B. L'échange a été créé par la sous couche MAC2ExchSubLayer. Il possède un ID bien déterminé.

Device A

Device B

Appli

ExchangeCtrl

Appli

ExchangeCtrl

2- Create Exch n°x

4- Create Exch n°y

3- Req (ID=x)

5- Req

1- Req (ID=x)

6- Data

7- Kill Exch n°y

8- Data (ID=x)

9- Data

10- Kill Exch n°x

3’- retry n

Req

Data

Fig x : échange typique d'une requête : focus sur le récepteur, renvoie de donnée

L'acquittement est sensiblement identique, c'est pourquoi l'illustration de l'échange de type Message asynchrone + acquittement n'est pas détaillé. Se reporter directement à la FSM associée un peu plus loin.

### La state Machine Data_FSM

### La state Machine Acq_FSM

# Les couches MAC et Phy_UART

## Approche générale

On s'intéresse ici à la couche i qui échange avec la couche i+1. Par exemple la MAC avec ExchangeLayer, ou bien Phy_UART avec MAC.

La couche i doit contenir :

- une variable structurée Message contenant les messages up et down et les flags associés ainsi qu'un statut,
- une FSM montante pour la réception vers la couche n+1, une FSM descendante pour l'émission vers la couche n-1
- Des fonctions IO qui sont proposées à la couche n+1 pour l'interface

### La couche MAC, vue globale

char Status

Couche MAC

char StrReceived[30?]

MAC_Mssg

char NewStrReceived

char StrToSend[30?]

char NewStrToSend

MAC_RecFSM

char State

Trans_Struct

MAC_SendFSM

char State

Trans_Struct

char MAC_IsNewMssg ()

Void MAC_GetNewMssg (char * ) // recopie le newmssg à l'@ indiquée

void MAC_SendNewMssg (char *) // recopie le mssg dont l'@ est donnée ds StrToSend. La FSM de transmission sera lancée (encapsulation, attente medum libre)

### La couche PhyUART, vue globale

char StrReceived[30?]

PhyUART_Mssg

PhyUART_FSM

char State

??PhyUART_SendFSM

char State

Trans_Struct

FSM & Init Fcts ...

char PhyUART_Init ()

char PhyUART_StartFSM()

char PhyUART_FSM_Progress ()

I/O Fcts ...

char PhyUART_IsNewMssg ()

void PhyUART_GetNewMssg (char *, int ) // recopie le newmssg à l'@ indiquée

void PhyUART_SendNewMssg (char *, int) // transmission directe à UART_FSK pour un print.

Couche PhyUART

char LenStrReceived

char NewStrReceived

char StrToSend[30?]

char LenStrToSend

char NewStrToSend

char Status

char Error

char InComingMssg[30?]

NB : Le tableau IncomingMssg est celui qui est mis à jour par la FSM de réception au fur et à mesure de l'arrivée d'octets depuis l'UART.

NB : il existe d'autres fonctions plus secondaires que celles données à l'interface (voir code ou diagramme de classe)

# La couche PhyUART

## Rôle

Réception :

- filtrer les messages dont l'entête est #####
- vérifier la longueur et le checksum, si OK, la trame est disponible pour transfert vers la couche supérieure
  NB : le processus de réception se fait par FSM. Dès qu'un préambule est détecté, le statut de la couche passe à MessgInComing, ce qui permet à la couche MAC de savoir que le médium n'est pas disponible. Le statut par défaut est listening.

Emission :

- calculer le checksum et la longueur du message
- encapsuler le message descendant
- Transmettre par une simple boucle.

NB : la couche MAC aura pris soin de vérifier que le médium est libre

## FSM de réception

La FSM scrute en permanence l'arrivée de l'entête ##### puis constitue l'ensemble de la chaîne de caractère. La trame reçue est :

|#####|Len|My@|Dest@|ID|Type_LenData|Data|Trial|CheckSum|

Si le checksum est correct, la chaîne PhyUART_Mssg.StrReceived[] vaut

|My@|Dest@|ID|Type_LenData|Data|Trial|

L'indicateur PhyUART_Mssg.NewStrReceived passe à 1.

### Les longueurs :

Au niveau entrée Phy_UART, la longueur correspond aux data + Len + CheckSum. Le maximum est fixé en #define StringLenMax :

StringLenMax

|#####|Len|My@|Dest@|ID|Type_LenData|Data|Trial|CheckSum|

Au niveau de la sortie de Phy_UART, la longueur est réduire de 2 (MACLenMax) :

MACLenMax

|#####|Len|My@|Dest@|ID|Type_LenData|Data|Trial|CheckSum|

### L'état UpdateMssgForMAC

Lors de la mise à jour, la chaîne PhyUART_Mssg.StrReceived est mise à jour par la recopie de IncomingMssg[]. Attention, seul le nombre de caractères samplés est recopié... Ainsi, est il impératif de disposer aussi de la longueur pour traiter correctement la chaîne (un résidu d'un ancienne peut en effet traîner dans la chaîne ...)

## L'émission

Elle se fait par la fonction void PhyUART_SendNewMssg (char * AdrString, int Len). Son rôle est juste d'écrire dans l'interface (StrToSend) , et d'indiquer son arrivée.

La FSM fait le reste : elle encapsule la donnée (#####Len ….data … CheckSum). Elle calcule le checkSum.

NB : l'émission physique se fait dans la FSM donc l'IT correspondante est prolongée à ce moment là, ce qui bloque toute réception.

## L'interface logicielle PhyUART/MAC, quelques informations ...

### Les vérifications faites par les fonctions IO de PhyUART

Les fonctions renvoient -1 si malfonction, 0 sinon.

int PhyUART_GetNewMssg (char * AdrString, int Len);

Erreur si Len est trop petite, précisément si Len est inférieure strictement à StringLenMax-2 (define .h). En effet, le tableau de réception doit pouvoir contenir la plus grande taille de message reçu. Le tableau de réception est rempli à partir de IncomingMssg. Les caractères suivants sont complétés avec des 0 :

AdrDtring : |I|n|c|o|m|i|n|g|M|s|s|g|0|0|0.....|0|0|

int PhyUART_SendNewMssg (char * AdrString, int Len);

Erreur si Len est trop grande, précisément si Len est supérieur strictement à StringLenMax-2 (define .h)

### Les erreurs renvoyée par la FSM

Durant le processus de réception, plusieurs erreurs peuvent être rencontrées :

Au niveau Phy :

- NoError : tout va bien,
- LenError : La longueur de la chaîne reçue au niveau UART est soit :
  - Trop grande, précisément, supérieure strictement à StringLenMax (define .h),
  - Trop petite, précisément, inférieure strictement à StringLenMin (define .h). En effet, dans notre cas, la chaîne doit contenir au moins Len, @src, @dest,ID, Type_LEN,Trial, CheckSum, soit 7 otctets.

Aucun échantillonnage ne se fait dans IncomingMssg.

- CheckSumError : la détection du header est passé, l'échantillonnage dans IncomingMssg a eu lieu, mais la vérification du checksum a échoué,
- TimeOutError : la trame a commencée à être reconstituée dans IncomingMssg mais elle n'a pas été remplie dans le temps imparti. Le timeout est automatiquement ajusté en fonction du débit de la liaison série. Il est calculer à +10% de la longueur maximale pouvant être reçu.
- CheckSumError : cette erreur survient au moment de la mise à jour du flag de réception : si ce dernier était déjà à 1, ce code erreur est activé. Cela signifie que le dernier message n'a pas été lu.

## Timing FSM

Les tests (voir 6.6) montrent que le timing d'appel à PhyUART_FSM_Progress() ne peut pas être inférieur à 15µs pour prendre un peu de marge.

NB : CPU à 72MHz, Carte Nucléo 103

L'exécution de la FSM sera originale : La PhyUASRT_FSM passera en paramètre un Timer et une priorité. La FSM le module PhyUART va lui-même gérer son temps de scrutation en fonction de l'état dans lequel il est.

Les dépendance sont donc les suivantes :

La fonction Delay_ms (module FctDiverses) est logicielle (boucle), non dépendante du uC, mais dépendant de la compilation et de la vitesse CPU, ici 72MHz.

Les deux modules USART_FSK et MyTimer sont dépendants du µcontrôleur.

### Logique de réception

La figure ci dessous montre la FSM en indiquent les temps de chaque activité.

La FSM passe l'essentiel de son temps en phase WaitForHeader. La transition HeaderOK est confiée au callback UART. Ce dernier a donc pour mission de détecter 5# d'affilé, ce qui prend au maximum 50Ts soit 1300µs à 38400 Bds → On fixera donc l'échantillonnage en phase WaitForHeader à 1ms. Rien ne sert d'aller plus vite.

Quand le Header a été détecté (callback UART), l'échantillonnage est accéléré à 100µs pour ne pas manquer un caractère dans la phase readingframe ( 1 caractère à 38400 Bds = 260µs)

Le reste sera aussi à 100µs.

On sait très bien que SendMssg va déborder donc bloquer l'IT plus longtemps, pas grave.

L'idée est que la période « inutile » de scrutation pèse peu sur le CPU, soit quelques µs sur 1ms.

Antenne

rea12345#####9messagejrtuip0 ert #####6Hellop

Tx Frame

#####6Hellop

rea12345#####9messagejrtuip0 ert

IT UART

IT FSM

Rx Frame

State

1

3

Conf

Rec /em

2

4

Légende

State : WaitForHeader

State : ReadingFrame

State : CheckSum

State : UpdateMssgForMAC

State : Framing

State : SendMssg

- Au départ, l'état est WaitForHeader, la clk FSM est de 1ms,
- Au cours de cette phase, le callback UART commence à accumuler des #, en tps réel UART
- (1) le header est détecté (5# détectés),
- (2) le timer est accéléré à 10µs, on passe à l état ReadingFrame.
- (3) le dernier caractère est lu en ReadingFrame, on passe en checksum en prenant soin de remettre Clk FSM à 1ms. Puis on passe à l'étape de mise à jour.
- (4) une émission est déclenchée, on passe en état Framing. Enfin l'émission a lieu : elle prolonge gravement l'IT, mais finit obligatoirement par rendre la main. Mettre un watchdog ?

### Améliorations en cours de mise au point :

Une option est possible dans le driver bas niveau UART : #define UseCarrierDetect

Cette option configure une interruption externe sur /CD. Celle-ci est de plus haute priorité. Son rôle est d'autoriser ou non les interruptions UART. Cela ne se fait pas par le NVIC ou même RXNEIE. Cela provoque de grave dysfonctionnements. Le choix qui s'impose est de jouer sur RE (Receive Enable). Là ça marche très bien.

→ les IT UART sont clairement moindre et donc, la CPU est grandement soulagée.

## Tests logiciels

### Test de base uC + PC XCTU direct UART1 (pas de FSK)

Les chronométrages sont fait en réel avec Analog discovery : Mesure de largeur d'impulsion.

Incoming message 30 de longueur (28 utile), donc condition maximale : OK

Chronométrage sur réception caractère (state = ReadingFrame) : 1,3µs

Chronométrage sur checksum(state = CheckSum) : 11,8µs

Chronométrage sur update (state = UpdateMssgForMAC) : 13,2µs

### Test complet de la couche PhyUART, Nucléo 103

- request

- AsyMssg

- data

- Ack

- request

- AsyMssg

- data

- Ack

UART (Phy 2)

Master

FSK (Phy 1)

Phy_UART

- request

- AsyMssg

- data

- Ack

Phy Frame

|#####|Len|datal|CheckSum|

MAC Frame

|Len'|datal|

UART (Phy 2)

Slave

FSK (Phy 1)

Phy_UART

- request

- AsyMssg

- data

- Ack

- request

- AsyMssg

- data

- Ack

- request

- AsyMssg

- data

- Ack

### Scénario de test 1

On utilise un LCD

3 acteurs : Master et Slave (cartes réseau capteur) + PC et boîtier

Master

première ligne « i am the master »

seconde ligne : ce qu'il reçoit.

Quand il reçoit il renvoie le message « Still Master » après 1 sec

Slave

première ligne « waiting mssg »

seconde ligne : ce qu'il reçoit.

Séquence :

PC en Tx, il envoie un message

Il est reçu par les deux uC

PC est basculé rapidement en Rx

le Master envoie alors son message vers le Slave et aussi le PC.

Bilan (Ref commit git ) : 69cbd65

OK à 9600 bds

### Scénario de test 2

Le Master

- envoie 1, 2,3 etc.... en affichant sur le LCD ligne 0
- affiche toujours ce qu'elle reçoit en ligne 1
- un champ Erreur est créé : si lors de l'émission le code reçu juste avant n'est pas égale au code ôté de 1, alors le champ s'incrémente. Ainsi, si aucune erreur n'est détectée c'est que :
  - le master a bien envoyé,
  - le slave a bien reçu,
  - le slave a bien renvoyé après 200ms,
  - le master a bien reçu.

Le slave

- affiche ce qu'il reçoit en ligne 0
- renvoie ce qui est reçu et le précise en ligne 1, le tout avec un décalage de 200ms.

Bilan :

Test bureau – garage.

→ à 9600 Bds, on constate 10 erreurs sur 1400 transactions.

→ 38400 Bds, on constate 2 erreurs sur 2250 transactions.

→ on privilégiera donc 38400 Bds à la fois pour l'économie d'NRJ et pour la fiabilité. NB : on constate le même taux d'erreur avec les modules à 50cm l'un de l'autre !

# La couche MAC

## Généralités

On décide, pour un gain en vitesse, d'inclure la fonctionnalité MAC dans le module PhyUART. La fonctionnalité est essentiellement ajoutée dans l'état UpdateMssgForMAC (cf fig ci-dessous). Le module est renommé MACPhyUART.c/.h.

Le filtrage d'adresse est donc fait au moment de la mise à jour. La structure PhyUART_Mssg est complété par des champs propres à MAC :

### Emission

La fonction int MACPhyUART_SendNewMssg (char DestAdr, char * AdrString, int Len) vient tester la longueur pour vérifier qu'elle n'est pas trop grande.

Ensuite, la fonction insère dans PhyUART_Mssg.StrToSend l'adresse My, puis l'adresse de destination passée en argument. L'ensemble de la chaîne est alors complétée.

### En réception

Le filtrage d'adresse est donc fait au moment de la mise à jour. La structure PhyUART_Mssg est complété par des champs propres à MAC :

MACMatch : flag indiquant que l'adresse destination du message est celle de My,

My : Adresse MAC propre du module

MACStrReceived : les data du message (les adresses sources et destinations sont enlevées)

NB : StrReceived : string en sortie couche Phy incluant les deux adresses + datas. Sont enlevées la longeur du message initial reçu par l'UART (LEN) et le checksum (d'où le -2 dans la longueur et le -4 dans la longueur MAC String)

MACLenStrReceived : la longueur effective des data au niveau MAC

MACNewStrReceived : le flag indiquant qu'un nouveau String MAC est arrivé

MACSrcAdress : L'adresse source du message, à lire par l'application.

## Les fonctions de la couche MAC

Les fonctions sont ajoutées à PhyUART. Elles ne les remplacent pas. Au User de choisir s'il veut travailler avec une couche (PhyUART) ou les deux (MAC et PhyUART). Dans ce dernier cas on se focalise uniquement sur les fonctions MAC, on n'utilise rien d'autre.

Les fonctions :

La fonction MACPhyUART_StartFSM est juste un redéfinition de PhyUART_StartFSM.

Précisons que la fonctionnalité CSMA (Carrier Sense Multiple Acces) est propre à l'architecture de la FSM au niveau Phy : l'émission n'est possible que si l'état n'est « listening », donc l'accès en émission se fait uniquement si le système ne reçoit pas.

## Point sur les longueurs

Message provenant de l'UART

- Forme |##### |Len | Data |CheckSum|
- Maximum pour Len = StringLenMax (=30), les ##### ne sont pas comptés

IncomingMssg[ ]:

- Forme |@Src|@Dest|Data'|CheckSum| (Data = |@Src|@Dest|Data'| )
- Longueur LIncomingMssg = Len-1 (=29 max), L'octet Len n'apparaît plus dans IncomingMssg

.StrReceived[ ] :

- Forme |@Src|@Dest|Data'|
- Longueur : LStrReceived = LIncomingMssg -1 = Len-2 (=28 max),

.MACStrReceived[ ] :

- Forme |Data'|
- Longueur : LMACStrReceived = LStrReceived -2 = Len-4 (=26 max),

## Architecture logicielle incluant la couche MAC

Indépendant du matériel

dépendant du matériel

## Les essais de validation

### Contexte, Nucléo 103

StringLenMax

- request

- AsyMssg

- data

- Ack

- request

- AsyMssg

- data

- Ack

UART (Phy 2)

Master My 0xAA

FSK (Phy 1)

MACPhyUART

- request

- AsyMssg

- data

- Ack

Phy Frame

|#####|Len|datal|CheckSum|

UART (Phy 2)

Slave My OxBB

FSK (Phy 1)

MACPhyUART

- request

- AsyMssg

- data

- Ack

- request

- AsyMssg

- data

- Ack

- request

- AsyMssg

- data

- Ack

### Scénario de test 3

Le ping pong, c'est à dire le test 2 précédent mais avec la couche MAC (0xAA communicant avec 0xBB).

Test passé, identique au test 2 sans la MAC .

Taux d'erreur 4/1860 à 38400Bds, appareils à 50cm. (Rem : environnement peut être bruité par la grue d'à côté …).

### Scénario de test 4

Pingpong entre la chaîne MAC la plus longue possible : 26 de long. OK émission et réception.

Tentative à 27 : rien n 'est envoyé.

Test OK.

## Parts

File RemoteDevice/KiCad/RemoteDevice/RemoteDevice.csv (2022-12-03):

Source: | C:\Users\trocache\Documents\Thierry\2013_2016\Projets_perso\2022_AutoConsoPerso\PVLoadsManagementSyst\RemoteDevice\KiCad\RemoteDevice\RemoteDevice.kicad_sch
Date: | 12/06/2022 21:46:08
Tool: | Eeschema (6.0.2)
Generator: | C:\Program Files\KiCad\6.0\bin\scripting\plugins/bom_csv_grouped_by_value_with_fp.py
Component Count: | 55
Ref | Qnty | Value | Cmp name | Footprint | Description | Vendor
C1, C12, C13, C18, | 4 | 10u | C_Polarized | Capacitor_Tantalum_SMD:CP_EIA-7132-20_AVX-U | Polarized capacitor
C2, C4, | 2 | 2.2u | C | Capacitor_SMD:C_1812_4532Metric | Unpolarized capacitor
C3, | 1 | 4.7u | C | Capacitor_SMD:C_1812_4532Metric | Unpolarized capacitor
C5, C7, C11, C16, | 4 | 100n | C | Capacitor_SMD:C_1206_3216Metric | Unpolarized capacitor
C6, C15, | 2 | 10u | C | Capacitor_SMD:C_1812_4532Metric | Unpolarized capacitor
C8, C9, C10, | 3 | 47p | C | Capacitor_SMD:C_0805_2012Metric | Unpolarized capacitor
C14, C17, | 2 | 10n | C | Capacitor_SMD:C_1206_3216Metric | Unpolarized capacitor
D1, D2, | 2 | SFH4544 | SFH4546 | LED_THT:LED_D5.0mm_IRGrey | High-Power IR LED 940nm
D3, D4, | 2 | BAT43W-V | BAT43W-V | Diode_SMD:D_SOD-123 | 30V 0.2A Small Signal Schottky diode, SOD-123
J1, | 1 | Alim | Conn_01x02_Male | LibKiCad_PjtDeviceManagePV:PinHeader2pts | Generic connector, single row, 01x02, script generated (kicad-library-utils/schlib/autogen/connector/)
JP1, JP2, JP3, JP4, | 4 | SolderJumper_2_Open | SolderJumper_2_Open | Jumper:SolderJumper-2_P1.3mm_Open_TrianglePad1.0x1.5mm | Solder Jumper, 2-pole, open
L1, | 1 | 4.7u | L | Inductor_SMD:L_Abracon_ASPI-3012S | Inductor
Q1, Q2, | 2 | Q_PMOS_GSD | Q_PMOS_GSD | Package_TO_SOT_SMD:SOT-23 | P-MOSFET transistor, gate/source/drain
R1, R3, R7, R8, | 4 | 10k | R | Resistor_SMD:R_1206_3216Metric | Resistor
R2, | 1 | 47k | R | Resistor_SMD:R_1206_3216Metric | Resistor
R4, | 1 | 47 | R | Resistor_SMD:R_1206_3216Metric | Resistor
R5, | 1 | 220k | R | Resistor_SMD:R_1206_3216Metric | Resistor
R6, | 1 | 1k | R | Resistor_SMD:R_1206_3216Metric | Resistor
R9, | 1 | 5.6k | R | Resistor_SMD:R_1206_3216Metric | Resistor
R10, | 1 | 100k | R | Resistor_SMD:R_1206_3216Metric | Resistor
R11, R13, | 2 | 2.2k | R | Resistor_SMD:R_1206_3216Metric | Resistor
R12, | 1 | 4.7k | R | Resistor_SMD:R_1206_3216Metric | Resistor
SW1, SW2, | 2 | BP | SwitchBP | LibKiCad_PjtDeviceManagePV:SW
U1, | 1 | XC9140 | XC9140 | Package_TO_SOT_SMD:SOT-23-5 | boost converter
U2, | 1 | STM32L041F6Px | STM32L041F6Px | Package_SO:TSSOP-20_4.4x6.5mm_P0.65mm | ARM Cortex-M0+ MCU, 32KB flash, 8KB RAM, 32MHz, 1.65-3.6V, 15 GPIO, TSSOP-20
U3, U5, | 2 | MCP6281 | TL071 | Package_SO:SOIC-8_3.9x4.9mm_P1.27mm | Single Low-Noise JFET-Input Operational Amplifiers, DIP-8/SOIC-8
U4, | 1 | ADT7410TRZ | ADT7410TRZ | Package_SO:SOP-8_3.9x4.9mm_P1.27mm
U6, | 1 | RT606 | RT606 | LibKiCad_PjtDeviceManagePV:RT606
U7, | 1 | Microphone | Microphone | LibKiCad_PjtDeviceManagePV:Microphone
U8, | 1 | LD2981CU33 | LD2981CU33 | Package_TO_SOT_SMD:SOT-89-3_Handsoldering
U9, | 1 | Con_4pts | Con_4pts | LibKiCad_PjtDeviceManagePV:PinHeader4pts
U10, | 1 | XBEE-3 | XBEE-3 | INSA:XBEE-3-TH

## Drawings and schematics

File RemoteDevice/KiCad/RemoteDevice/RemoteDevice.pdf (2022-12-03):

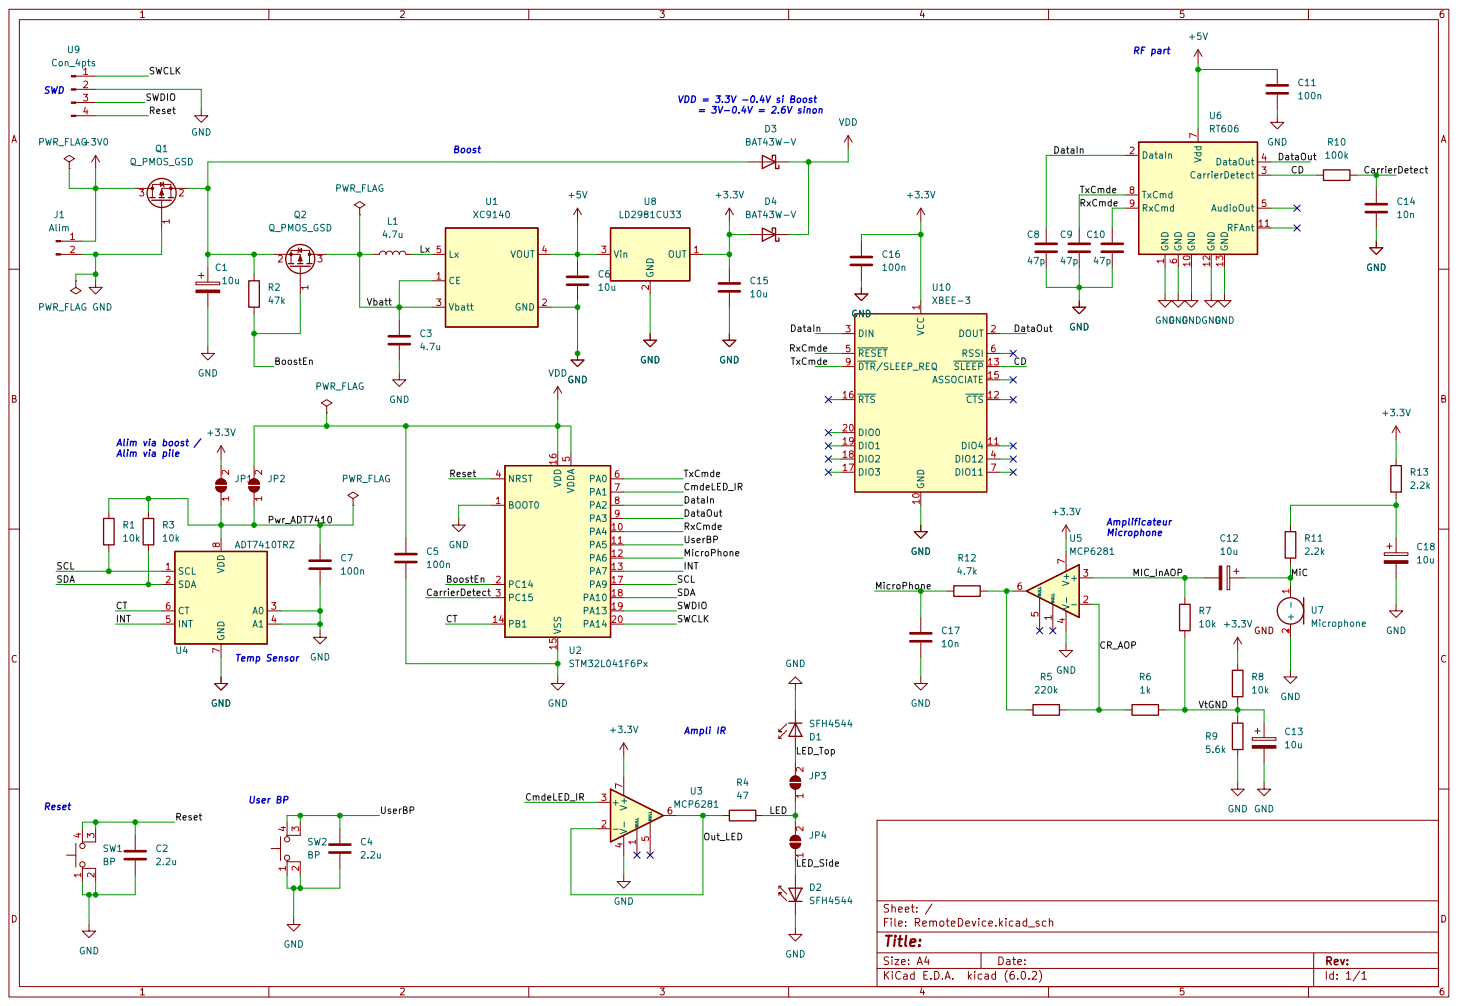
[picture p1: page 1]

47p PWR_FLAG
Microphone Boost Temp Sensor User BP Reset

1 GND 10 RFAnt 11 GND 12 GND 13 DataIn 2 CarrierDetect 3 DataOut 4 AudioOut 5 GND

1 GND 10 DIO4 11 ~{CTS}12 ~{SLEEP}13 ASSOCIATE 15 ~{RTS} 16 DIO3 17 DIO2 18 DIO1 19 DOUT 2 DIO0 20 DIN 3 DIO12 4 ~{RESET} 5 RSSI 6 DIO11 7 ~{DTR}/SLEEP_REQ 9 U10 XBEE-3 +3.3V C6

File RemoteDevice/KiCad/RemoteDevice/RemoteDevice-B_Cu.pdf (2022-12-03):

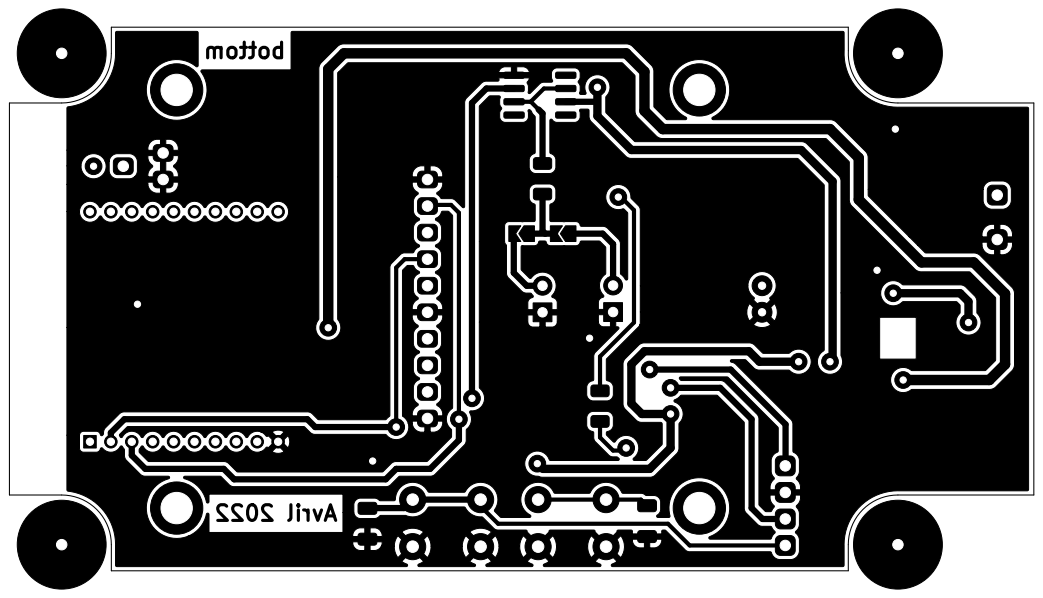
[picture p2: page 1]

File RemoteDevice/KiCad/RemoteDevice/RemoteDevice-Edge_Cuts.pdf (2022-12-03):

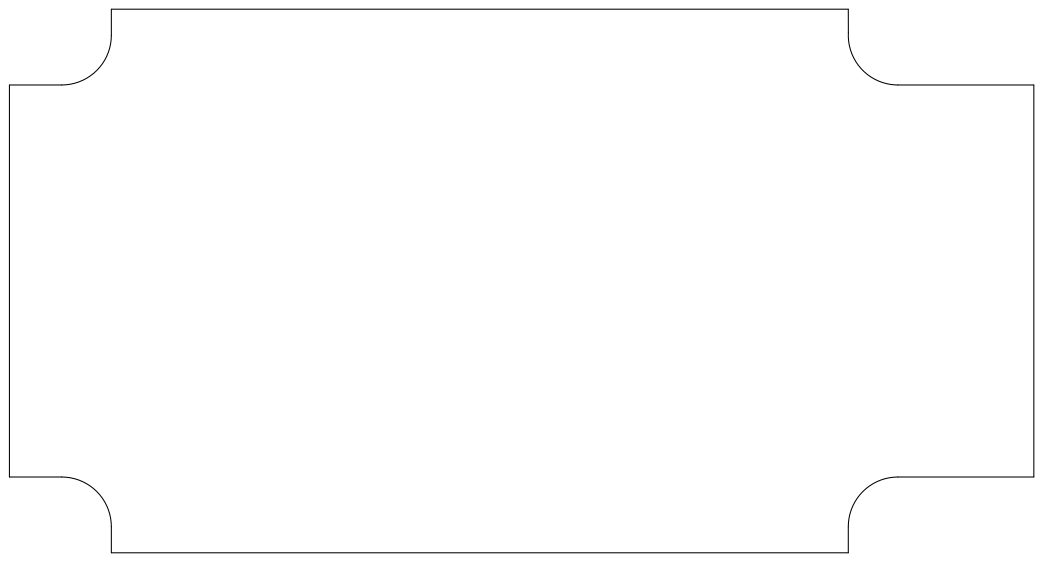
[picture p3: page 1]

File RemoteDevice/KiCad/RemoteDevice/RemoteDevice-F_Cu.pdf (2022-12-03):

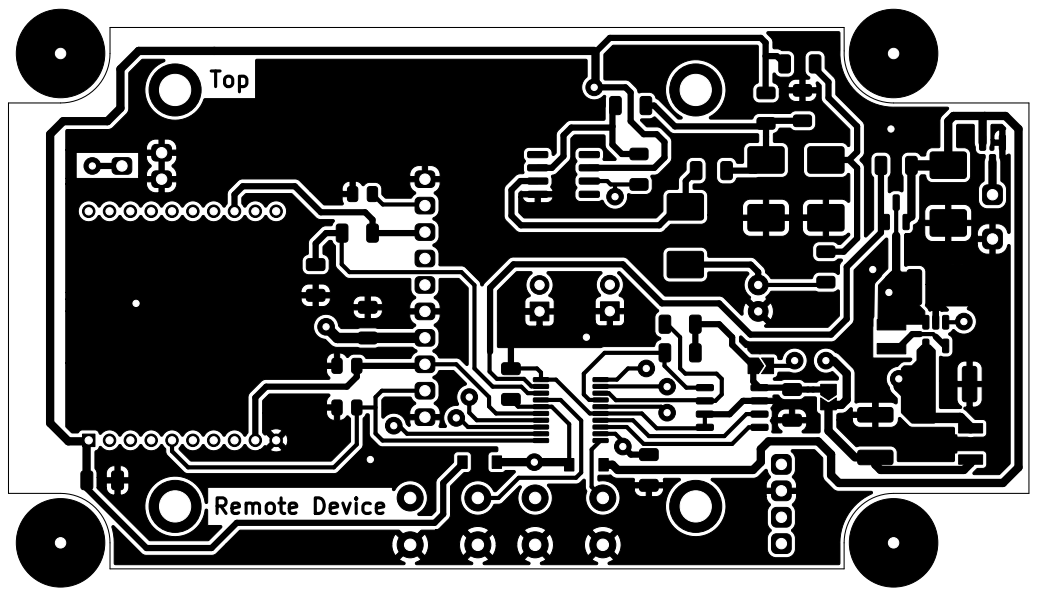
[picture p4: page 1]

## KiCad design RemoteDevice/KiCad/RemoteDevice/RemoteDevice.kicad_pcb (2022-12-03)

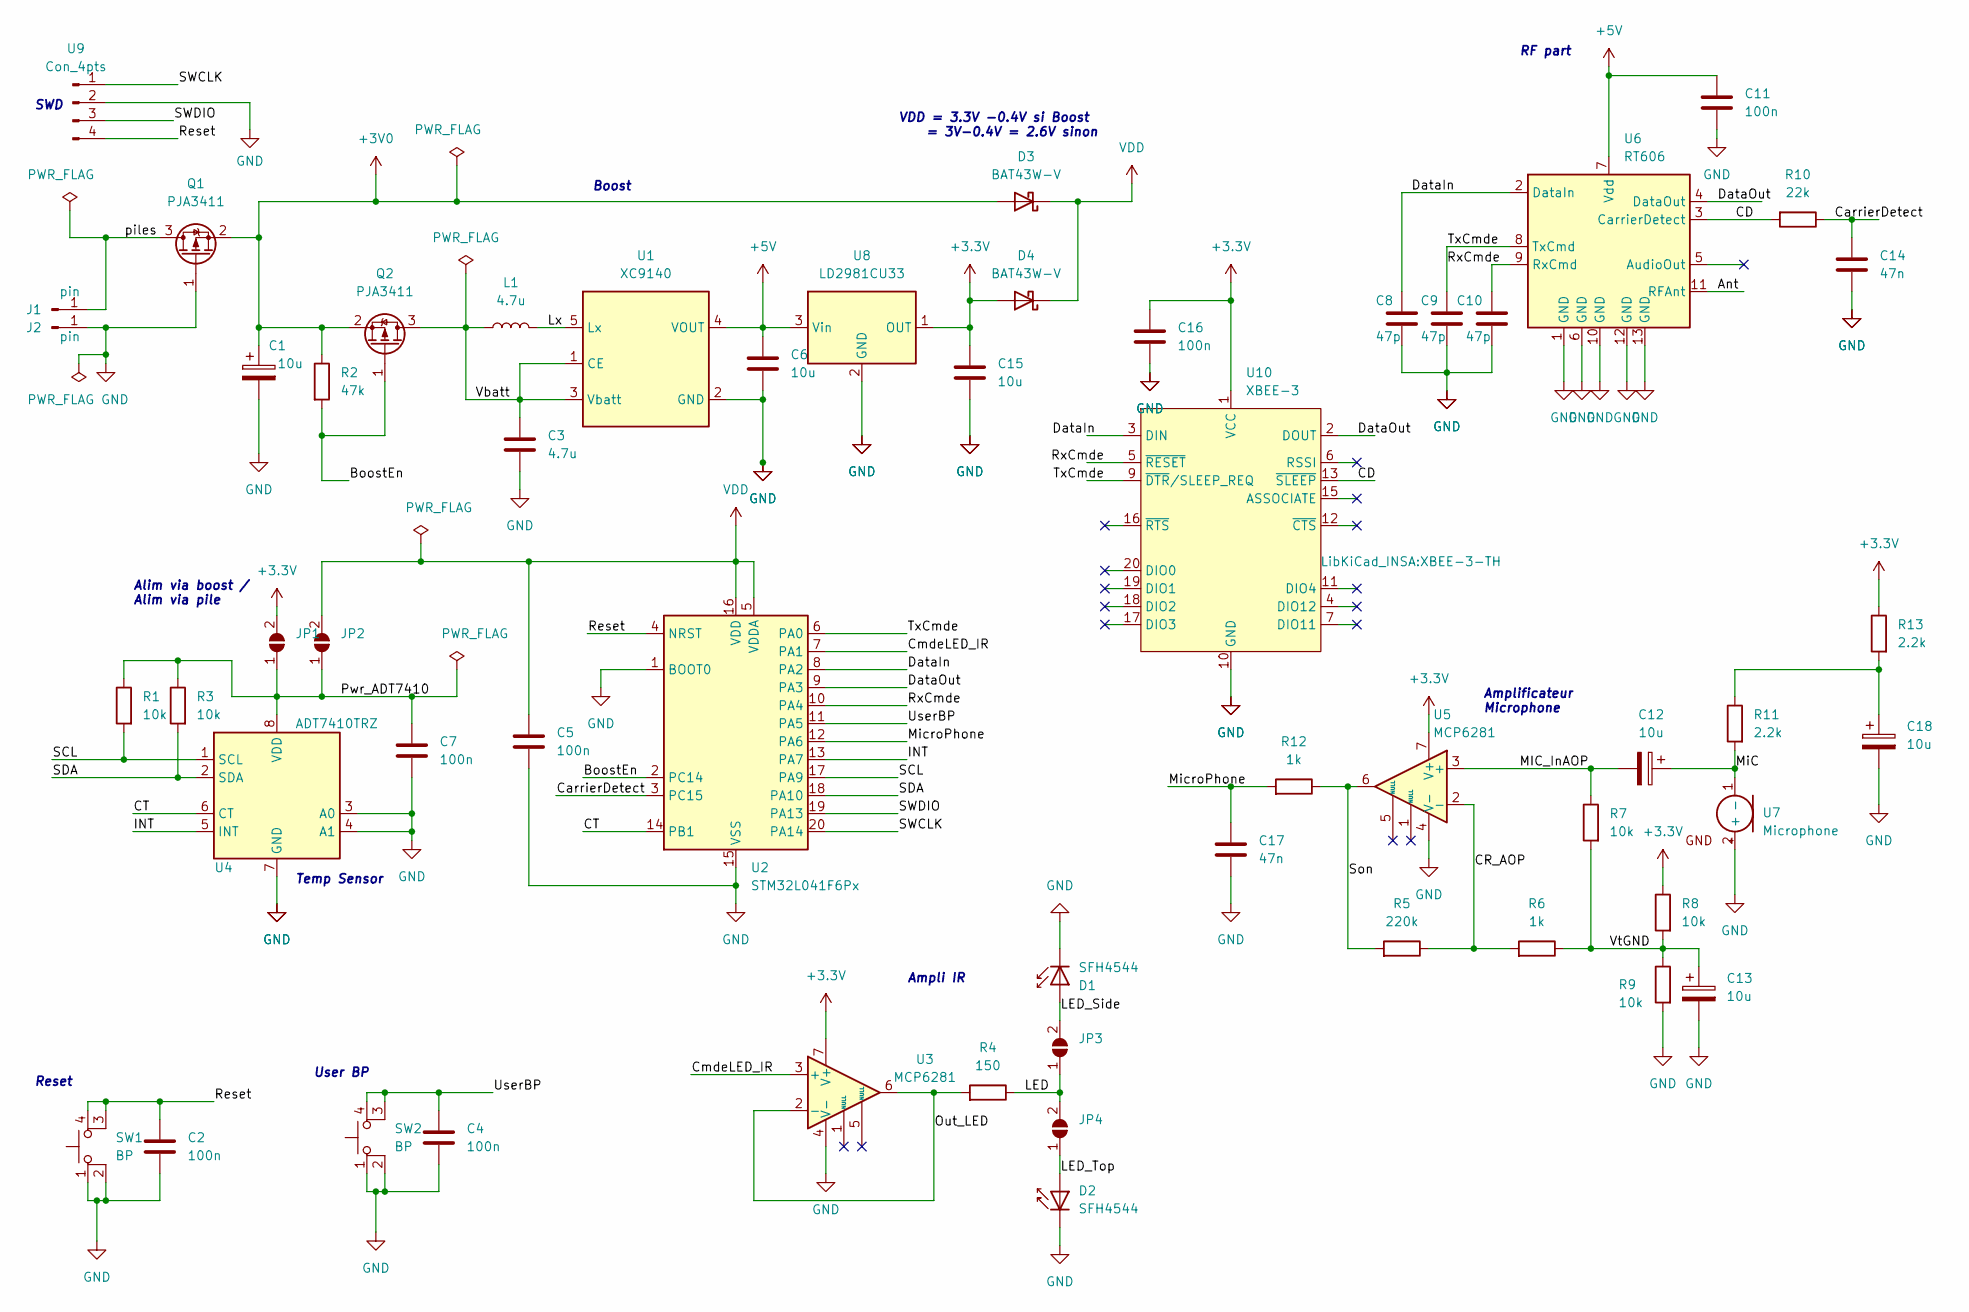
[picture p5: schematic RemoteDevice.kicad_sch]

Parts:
C1, C12, C13, C18: 10u; CP_EIA-7132-20_AVX-U
C2, C4, C5, C7, C11, C16: 100n; C_1206_3216Metric
C3: 4.7u; C_1812_4532Metric
C6, C15: 10u; C_1812_4532Metric
C8, C9, C10: 47p; C_0805_2012Metric
C14, C17: 47n; C_1206_3216Metric
D1, D2: SFH4544; LED_D5.0mm_IRGrey
D3, D4: BAT43W-V; D_SOD-123
J1, J2: pin; PinHeader1Pt
JP1, JP2, JP3, JP4: SolderJumper_2_Open; SolderJumper-2_P1.3mm_Open_TrianglePad1.0x1.5mm
L1: 4.7u; L_Abracon_ASPI-3012S
Q1, Q2: PJA3411; SOT-23
R1, R3, R7, R8, R9: 10k; R_1206_3216Metric
R2: 47k; R_1206_3216Metric
R4: 150; R_1206_3216Metric
R5: 220k; R_1206_3216Metric
R6, R12: 1k; R_1206_3216Metric
R10: 22k; R_1206_3216Metric
R11, R13: 2.2k; R_1206_3216Metric
SW1, SW2: BP; SW
U1: XC9140; SOT-23-5
U2: STM32L041F6Px; TSSOP-20_4.4x6.5mm_P0.65mm
U3, U5: MCP6281; SOIC-8_3.9x4.9mm_P1.27mm
U4: ADT7410TRZ; SOP-8_3.9x4.9mm_P1.27mm
U6: RT606
U7: Microphone
U8: LD2981CU33; SOT-89-3_Handsoldering
U9: Con_4pts; PinHeader4pts
U10: XBEE-3; XBEE-3-TH

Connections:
+3V0: C1.1, D3.2 (A), Q1.2 (S), Q2.2 (S), R2.1
+3V3: C15.1, C16.1, D4.2 (A), JP1.2 (B), R8.1, R13.1, U3.7 (V+), U5.7 (V+), U8.1 (OUT), U10.1 (VCC)
+5V: C6.1, C11.1, U1.4 (VOUT), U6.7 (Vdd), U8.3 (Vin)
/Ant: U6.11 (RFAnt)
/BoostEn: Q2.1 (G), R2.2, U2.2 (PC14)
/CD: R10.2, U6.3 (CarrierDetect), U10.13 (~SLEEP)
/CR_AOP: R5.1, R6.2, U5.2 (-)
/CT: U2.14 (PB1), U4.6 (CT)
/CarrierDetect: C14.1, R10.1, U2.3 (PC15)
/CmdeLED_IR: U2.7 (PA1), U3.3 (+)
/DataIn: C8.1, U2.8 (PA2), U6.2 (DataIn), U10.3 (DIN)
/DataOut: U2.9 (PA3), U6.4 (DataOut), U10.2 (DOUT)
/INT: U2.13 (PA7), U4.5 (INT)
/LED: JP3.1 (A), JP4.2 (B), R4.1
/LED_Side: D1.2 (A), JP3.2 (B)
/LED_Top: D2.2 (A), JP4.1 (A)
/Lx: L1.1, U1.5 (Lx)
/MIC_InAOP: C12.2, R7.1, U5.3 (+)
/MiC: C12.1, R11.2, U7.1 (-)
/MicroPhone: C17.1, R12.2, U2.12 (PA6)
/Out_LED: R4.2, U3.2 (-), U3.6
/Pwr_ADT7410: C7.1, JP1.1 (A), JP2.1 (A), R1.1, R3.1, U4.8 (VDD)
/Reset: C2.1, SW1.3, SW1.4, U2.4 (NRST), U9.4
/RxCmde: C10.1, U2.10 (PA4), U6.9 (RxCmd), U10.5 (~RESET)
/SCL: R1.2, U2.17 (PA9), U4.1 (SCL)
/SDA: R3.2, U2.18 (PA10), U4.2 (SDA)
/SWCLK: U2.20 (PA14), U9.1
/SWDIO: U2.19 (PA13), U9.3
/Son: R5.2, R12.1, U5.6
/TxCmde: C9.1, U2.6 (PA0), U6.8 (TxCmd), U10.9 (~DTR/SLEEP_REQ)
/UserBP: C4.1, SW2.3, SW2.4, U2.11 (PA5)
/Vbatt: C3.1, L1.2, Q2.3 (D), U1.1 (CE), U1.3 (Vbatt)
/VtGND: C13.1, R6.1, R7.2, R8.2, R9.1
/piles: J1.1, Q1.3 (D)
GND: C1.2, C2.2, C3.2, C4.2, C5.2, C6.2, C7.2, C8.2, C9.2, C10.2, C11.2, C13.2, C14.2, C15.2, C16.2, C17.2, C18.2, D1.1 (K), D2.1 (K), J2.1, Q1.1 (G), R9.2, SW1.1, SW1.2, SW2.1, SW2.2, U1.2 (GND), U2.1 (BOOT0), U2.15 (VSS), U3.4 (V-), U4.3 (A0), U4.4 (A1), U4.7 (GND), U5.4 (V-), U6.1 (GND), U6.6 (GND), U6.10 (GND), U6.12 (GND), U6.13 (GND), U7.2 (+), U8.2 (GND), U9.2, U10.10 (GND)
unnamed: C18.1, R11.1, R13.2
VDD: C5.1, D3.1 (K), D4.1 (K), JP2.2 (B), U2.5 (VDDA), U2.16 (VDD)

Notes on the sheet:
Ampli IR
Boost
Reset
RF part
Alim via boost / Alim via pile
Amplificateur Microphone
VDD = 3.3V -0.4V si Boost = 3V-0.4V = 2.6V sinon
Temp Sensor
User BP
SWD

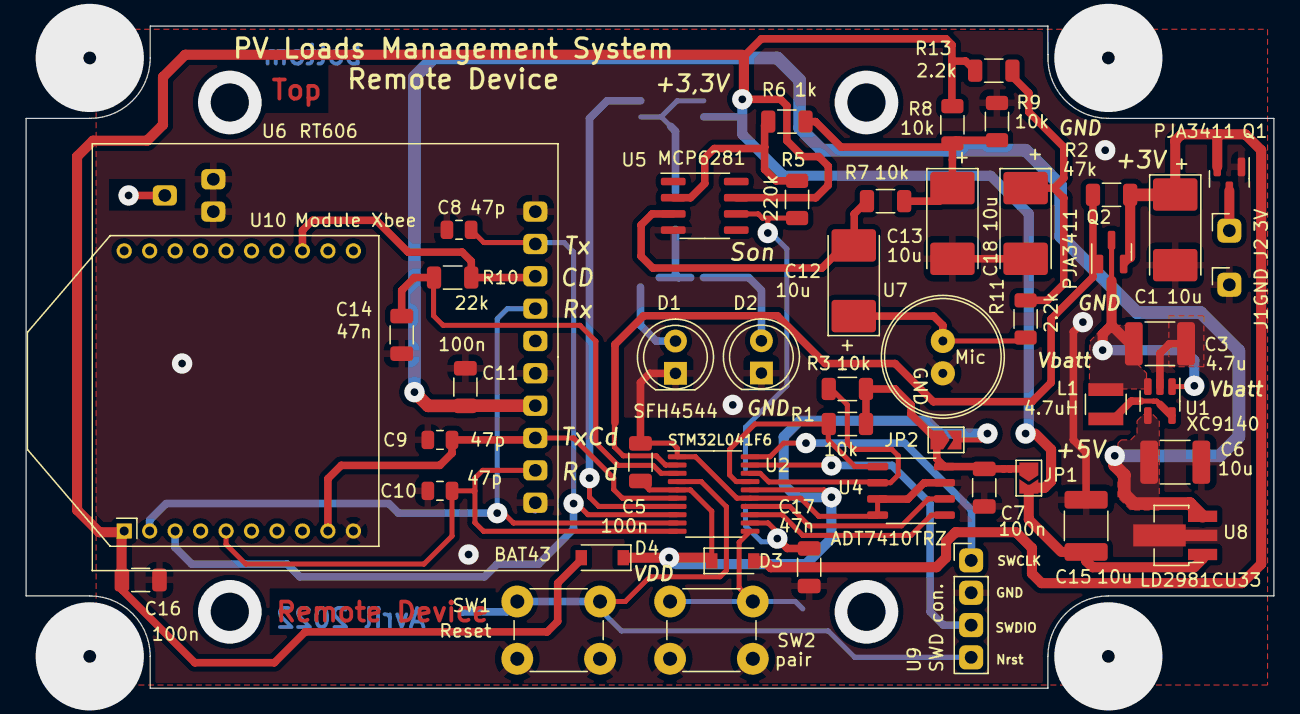
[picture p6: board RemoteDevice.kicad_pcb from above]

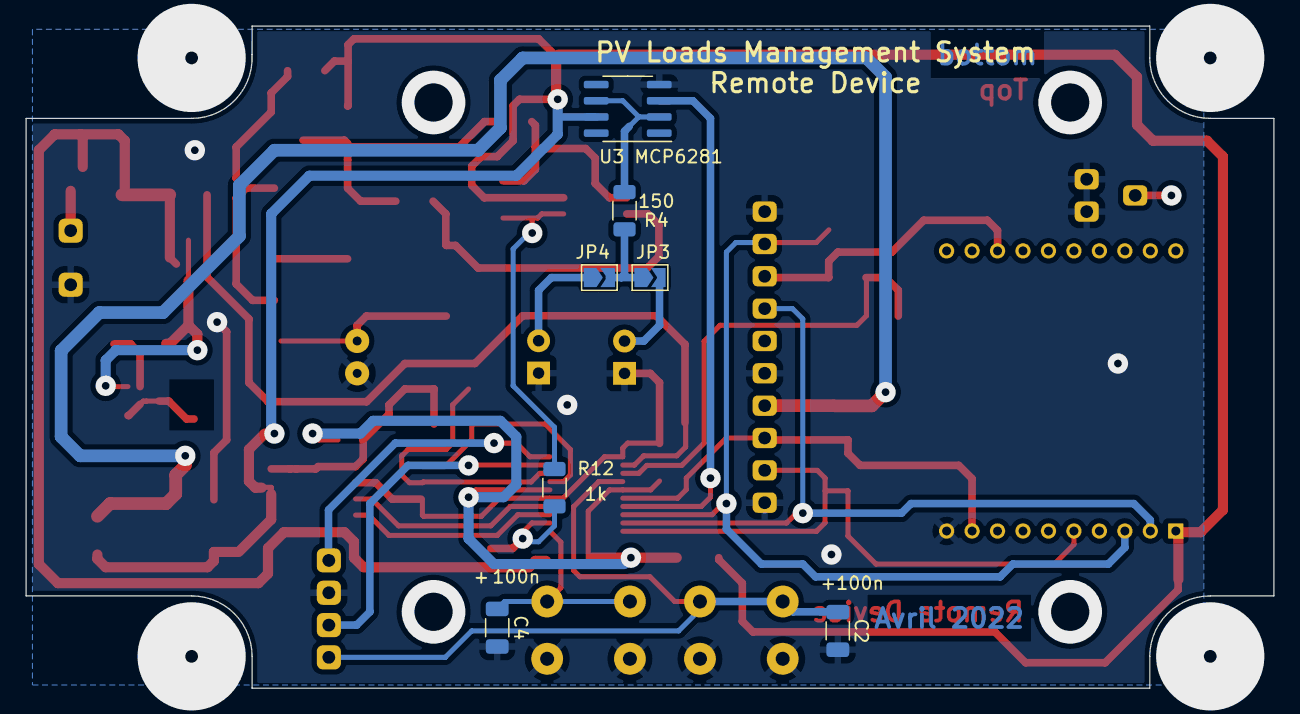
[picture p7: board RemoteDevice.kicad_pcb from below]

Board: 2 copper layers, 98.0 x 52.0 mm, 56 parts (7 on the bottom side), 36 nets.

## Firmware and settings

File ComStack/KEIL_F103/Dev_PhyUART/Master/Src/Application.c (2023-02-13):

#include "PhyUART.h"
#include "MyTimer.h"


#include "MyLCD.h"
#include "FctDiverses.h"
#include "clock.h"

/******************************************************************************************************************
	Master, test PhyUART
*****************************************************************************************************************/


char Rec[30];
int Error,Res;
short int Cnt; // max 65535
int Reste;
char Alpha[6];


int CharToInt(char * Messg)
{
 int i;
 i=10000*(Alpha[0]-0x30)+1000*(Alpha[1]-0x30)+100*(Alpha[2]-0x30)+10*(Alpha[3]-0x30)+(Alpha[4]-0x30);
 return i;
 
}

void IntToChar(int Val)
{
	int i;
	Alpha[0]=Val/10000;
	Reste=Val%10000;
	Alpha[1]=Reste/1000;
	Reste=Reste%1000;
	Alpha[2]=Reste/100;
	Reste=Reste%100;
	Alpha[3]=Reste/10;
	Alpha[4]=Reste%10;
	Alpha[5]=0; // null
	
	for (i=0;i<5;i++)
	{
		Alpha[i]=Alpha[i]+0x30;
	}

	
}

void IT_1sec(void)
{
	Cnt++;
	IntToChar(Cnt);
	
	
	if ((Res+1)!=Cnt) Error++;
	
	MyLCD_Set_cursor(10, 0);
	MyLCD_Print(Alpha);
	
	PhyUART_SendNewMssg(Alpha,5);
	
	
}


int main (void)
{
	Cnt=0;
	Error=0;
	SystickStart(); // obligatoire pour la gestion des TimeOut à tous les étages...
	PhyUART_Init();
	PhyUART_StartFSM();
	
	MyLCD_Init();
	MyLCD_Clear();
		
	MyLCD_Set_cursor(0, 0);
	MyLCD_Print("Mast send:       ");
	MyLCD_Set_cursor(0, 1);
	MyLCD_Print("Receiving:       ");
		
	
	MyTimer_CkEnable(TIM1);
	MyTimer_Set_Period(TIM1, 7200-1, 10000-1 );
  MyTimer_IT_Enable( TIM1, 5, IT_1sec);	

	


  
	
	while(1)
	{
		if (PhyUART_IsNewMssg()==1)
		{
			if (PhyUART_GetNewMssg(Rec,30)!=-1)
			{
				MyLCD_Set_cursor(10, 1);
				MyLCD_Print(Rec);
				Res=CharToInt(Rec);
		
			}
		}
		
	}
}

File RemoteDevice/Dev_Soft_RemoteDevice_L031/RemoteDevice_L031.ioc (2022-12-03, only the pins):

PA0-CK_IN.GPIO_Label=TxCmde
Mcu.UserName=STM32L031F6Px
PC14-OSC32_IN.Signal=GPIO_Input
PC15-OSC32_OUT.GPIO_Label=CD
PA13.Signal=SYS_SWDIO
PA9.Signal=I2C1_SCL
PC15-OSC32_OUT.Signal=GPIO_Input
PA1.Signal=GPIO_Output
PA5.Signal=GPIO_Input
PA0-CK_IN.Signal=GPIO_Output
PB1.GPIO_Label=CT
PA1.GPIO_Label=LED_IR
PA2.Signal=USART2_TX
PA4.Signal=GPIO_Output
PA6.Signal=ADC_IN6
PB1.Signal=GPIO_Input
PA7.GPIO_Label=INT
PA5.GPIO_Label=UserBP
PA10.Signal=I2C1_SDA
PA14.Signal=SYS_SWCLK
PC14-OSC32_IN.GPIO_Label=Boost_EnInp
PA4.GPIO_Label=RxCmde
PA3.Signal=USART2_RX
PA7.Signal=GPIO_Input

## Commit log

2022-12-03 Reprise propre du pojet. Voir Alire.txt. Tout le travail précédent est dans ../Back
    [RemoteDevice.csv, RemoteDevice.kicad_pcb, RemoteDevice.kicad_sch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]
2022-12-04 démarrage SysML. Le premier use case est fait, le diag de seq de base est également construit. Poursuivre
2022-12-04 Bdd et ibd remote device OK. Reste à faire le diagramme de classe
2022-12-10 SysML avancé côté CU. un .odt est fait qu'il faudra passer en pdf et inclure dans le Sysml. Le protocole de com est bien entamé.
2022-12-11 Le fichier attaché est un odt, donc dynamique. Les messages de com sont faits, les diag de séquences aussi (pairing et run), l'architecture logicielle com peut commencer....
2022-12-15 Idée nouvelle, qui s'inspire des couches OSI.... pas gagné
2022-12-30 Systeme : Grosse avancée sur l'architecture de la pile de communication. L'odt est bien parti mais il faut l'avancer rapidement
2023-01-02 Système : avancement du principe de la pile
2023-01-03 Système : avancement de la pile, attaquer les FSM de la couche exchandeCtrl...
2023-01-05 Système : FSM Request et FSM Asynchronuous message faits. Reste à rédiger celui de réception
2023-01-07 Système : la partie réception des messages MAC faite, FSM Req, AsyMsg aussi. FSM réception en cours à finir. Document odt à poursuivre
2023-01-08 Système : attention, pb avec ExchInde, remplacé par ID dans la frame et on ajoute Index local pour l'échange voir p21. Réécriture...
2023-01-26 Systeme + Stack : Phy testé avec XCTU sur COM1. Len error, Timeout, normal, validés. A faire : le checksum
    [PhyUART.c, UART_FSK_103.h]
2023-01-29 System+Stack : Phy_UART, FSM de réception validé avec XCTU sur COM1. Voir rep TestDeValidation/X_CTU_Test_1. Finaliser les fcts d'interface avec MAC
2023-01-30 System+Stack : Enesmeble PuyUART Terminé, validation en cours. Chronométrages en cours pour savoir les occurrences d'IT. Test passé pour frame UART à 30 caractères
2023-02-01 Stack : version SendMessg fusionné dans la FSM. Code Master revu. Tester !
2023-02-04 System+Stack : on décale la détection du header dans l'IT UART de manière à soulager la scrutation de la FSM Phy_UART
2023-02-04 System+Stack : voir odt pour la nouvelle version. Le code est à poursuivre, grand ménage sur les répertoires
2023-02-05 System + Stack bien débuggé, reste : vérifier calcul différence TimeOut, mettre les priorité en define, tester le filtrage CD
2023-02-13 System+Stack : débugg de la détection porteuse, CD. Il ne faut pas gérer les IT via RXNE ou NVIC, il faut juste neutraliser la réception
2023-02-13 System+Stack : la couche PhyUART est OK, devra encore être améliorée par les fonctions disponibles, également faire un doc d'utilisation (différent du doc de conception et de test)
2023-02-15 System+Stack : les .h sont commentés, un user guide concernant la stack est commencé, OK pour la couche physique. Passer à la MAC
2023-02-18 System + Stack : reprise commit Master n def487e. Développement MAC ne modifiant / ajoutant des fct dans la lib PhyUART nommée maintenant MACPhyUART
2023-02-18 System+Stack : MAC bien avancée, tests ping pong concluant, approfondir tests aux limites de tailles, ajouter broadcast
2023-02-19 System+Stack : MAC presque finie, broadcast OK, pb erreur overrun réglé, doc de conception à continuer, test aux longueurs limites à faire
2023-02-25 System + Stack : version néttoyée, Stack limitée à la couche MAC. Odt de conception et UG à jour, SysML limité à MAC
2023-02-26 System + Stack : version FSK et UART dans deux fichiers séparés. Renommage des fichiers drivers avec l'extension _F103
2023-07-15 UC : ajout d'un doc de conception odt. Partie écran tactile difficile, traitée dans /formation, autre dossier, sysml avancé
2023-07-16 Soft : Demarrage développement Remote Device. Software, architecture démarrée, SysML modifié, cible STM32L031
